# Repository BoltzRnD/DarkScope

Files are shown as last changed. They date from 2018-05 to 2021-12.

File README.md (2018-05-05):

View this project on [CADLAB.io](https://cadlab.io/node/983). 

(DarkScope is Still under development and might take until December 2018 for its first Functional Release.)

Darkscope is an ATSAME70Q21 Based, Open Source and Open Hardware, 4 Channel Portable DSO with Features Such as

1. 3.5" to 7" TFT
2. Internal Storage Options* (64 Mb - 256 Mb)
3. External Storage Support (MicroSD Cards and USB)
4. PC Based Expanded UI for Elaborated and Better Visualizations*.
5. Touch Screen Interface(This will be added at last.)
6. USB Type C Rev interface for Charging and Data Transfer.
7. Up to  5* MSPS (At 1 Active Channel) 
8. Up to  1* MSPS (At 4 Active Channels)

(* Chances are these will be improved by optimizing the firmware on every newer release.)

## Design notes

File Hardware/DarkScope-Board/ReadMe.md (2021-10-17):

# Scope

# HW Sections
1. A Baseboard that hosts All Processing (MCu and Supporting Circuitry, Expansion Ports for- Active Probe Shields, LCD, Switches) (Board 1)
2. Base Active Probe Board. i.e- Analog Channel (Board 2)
3. Battery Management Circuit(BMC) with 1500mAh or more Battery(Board 3)
4. High Speed Active Probe(Board 4)
5. Upto 4 Channel Support (Exposing/Utilizing PA0, PA4, PA5, PA6) (On BaseBoard 1)
6. (Optional) I2C Based Switch Board.(On BaseBoard 1)

Note-
1. LCD "LED-A" connected to 5V for now, can be changed to vcc

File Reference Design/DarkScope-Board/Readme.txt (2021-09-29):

This Folder will be Updated with Schematics and Board Files For the Darkscope.

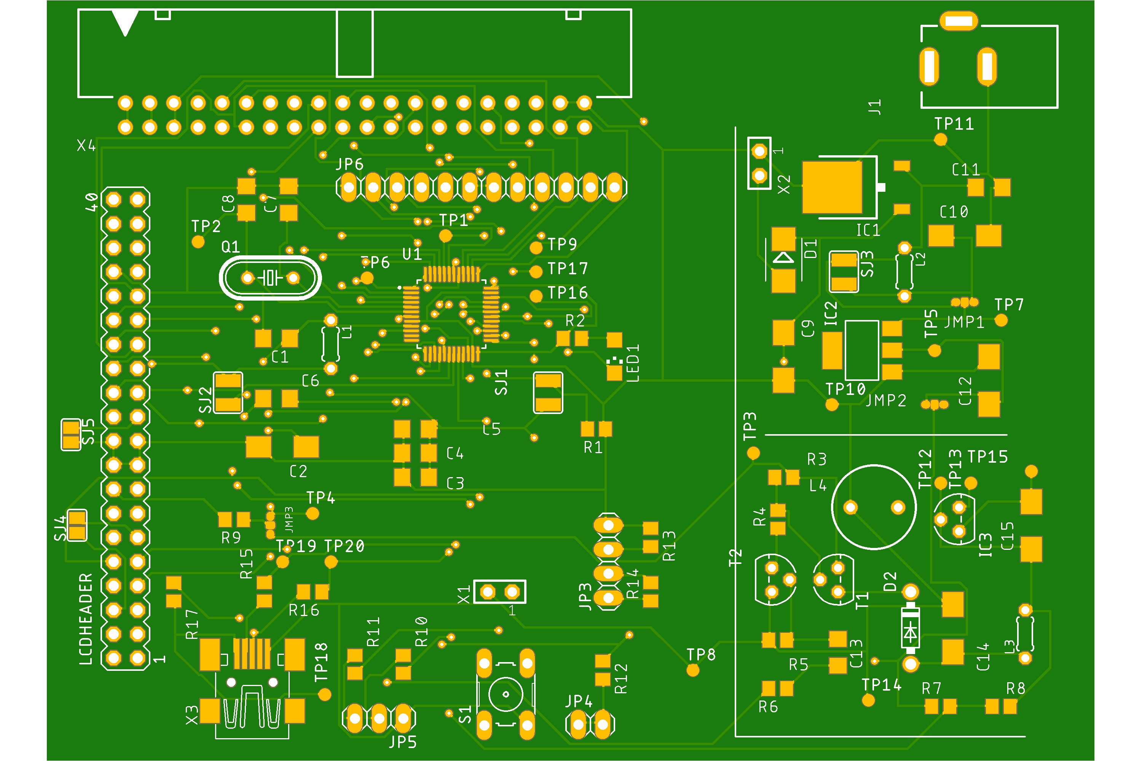
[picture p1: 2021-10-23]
Hardware/DarkScope-Board/BaseBoard.png

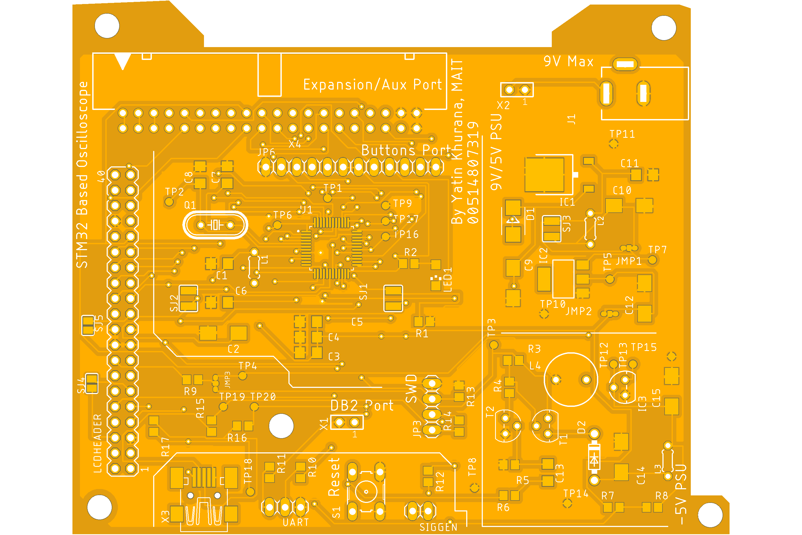
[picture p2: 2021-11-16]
Hardware/DarkScope-Board/BaseBoardOrange.png

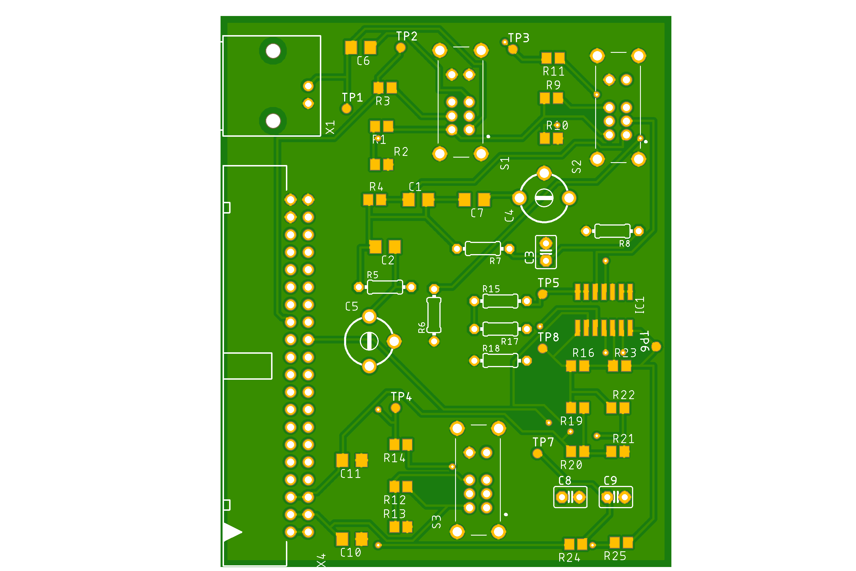
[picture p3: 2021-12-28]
Hardware/DarkScope-Board/Probe.png

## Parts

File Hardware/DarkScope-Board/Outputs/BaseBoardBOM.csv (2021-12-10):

Part | Value | Device | Package | Description | AVAILABILITY | DESCRIPTION | MF | MP | MPN | OC_FARNELL | OC_NEWARK | PACKAGE | POPULARITY | PRICE | PURCHASE-URL | SPICEPREFIX | TP_SIGNAL_NAME
C1 | 0.1u | C-EUC1206 | C1206 | CAPACITOR, European symbol |  |  |  |  |  |  |  |  | 54 |  |  | C
C2 | 100uF | CPOL-USCT6032 | CT6032 | POLARIZED CAPACITOR, American symbol |  |  |  |  |  |  |  |  | 0 |  |  | C
C3 | 0.1u | C-EUC1206 | C1206 | CAPACITOR, European symbol |  |  |  |  |  |  |  |  | 54 |  |  | C
C4 | 0.1u | C-EUC1206 | C1206 | CAPACITOR, European symbol |  |  |  |  |  |  |  |  | 54 |  |  | C
C5 | 0.1u | C-EUC1206 | C1206 | CAPACITOR, European symbol |  |  |  |  |  |  |  |  | 54 |  |  | C
C6 | 0.1u | C-EUC1206 | C1206 | CAPACITOR, European symbol |  |  |  |  |  |  |  |  | 54 |  |  | C
C7 | 22pF | C-EUC1206 | C1206 | CAPACITOR, European symbol |  |  |  |  |  |  |  |  | 54 |  |  | C
C8 | 22pF | C-EUC1206 | C1206 | CAPACITOR, European symbol |  |  |  |  |  |  |  |  | 54 |  |  | C
C9 | 100uF | CPOL-USCT6032 | CT6032 | POLARIZED CAPACITOR, American symbol |  |  |  |  |  |  |  |  | 0 |  |  | C
C10 | 100uF | CPOL-USCT6032 | CT6032 | POLARIZED CAPACITOR, American symbol |  |  |  |  |  |  |  |  | 0 |  |  | C
C11 | 0.1u | C-EUC1206 | C1206 | CAPACITOR, European symbol |  |  |  |  |  |  |  |  | 54 |  |  | C
C12 | 100uF | CPOL-USCT6032 | CT6032 | POLARIZED CAPACITOR, American symbol |  |  |  |  |  |  |  |  | 0 |  |  | C
C13 | 0.1u | C-EUC1206 | C1206 | CAPACITOR, European symbol |  |  |  |  |  |  |  |  | 54 |  |  | C
C14 | 100uF | CPOL-USCT6032 | CT6032 | POLARIZED CAPACITOR, American symbol |  |  |  |  |  |  |  |  | 0 |  |  | C
C15 | 100uF | CPOL-USCT6032 | CT6032 | POLARIZED CAPACITOR, American symbol |  |  |  |  |  |  |  |  | 0 |  |  | C
D1 | SS14 | ES2D | SMB | DIODE |  |  |  |  |  |  |  |  | 3
D2 | 1N5819-B | 1N5819-B | DO41-7.6 | 1.0A SCHOTTKY BARRIER RECTIFIER |  |  |  |  |  |  |  |  | 11
IC1 | 7805DT | 7805DT | TO252 | Positive VOLTAGE REGULATOR |  |  |  |  |  |  |  |  | 0
IC2 | REG1117 | REG1117 | SOT223 | 800mA and 1A Low Dropout (LDO) Positive Regulator |  |  |  |  | REG1117 | 1097566 | 14P6981 |  | 49
IC3 | 7905 | 79L05Z | TO92 | Negative VOLTAGE REGULATOR |  |  |  |  |  |  |  |  | 0
J1 | DCJ0202 | DCJ0202 | DCJ0202 | DC POWER JACK |  |  |  |  |  | unknown | unknown |  | 17
JMP1 | 0R-JUMPC | 0R-JUMPC | C0R-JMP | SMD 0R 0805 Jumper |  |  |  |  |  |  |  |  | 0
JMP2 | 0R-JUMPC | 0R-JUMPC | C0R-JMP | SMD 0R 0805 Jumper |  |  |  |  |  |  |  |  | 0
JMP3 | 0R-JUMPC | 0R-JUMPC | C0R-JMP | SMD 0R 0805 Jumper |  |  |  |  |  |  |  |  | 0
JP3 |  | PINHD-1X4 | 1X04 | PIN HEADER |  |  |  |  |  |  |  |  | 91
JP6 |  | PINHD-1X12 | 1X12 | PIN HEADER |  |  |  |  |  |  |  |  | 28
L1 | 100uH | L-US0204/5 | 0204/5 | INDUCTOR, American symbol |  |  |  |  |  |  |  |  | 0 |  |  | L
L2 | 100uH | L-US0204/5 | 0204/5 | INDUCTOR, American symbol |  |  |  |  |  |  |  |  | 0 |  |  | L
L3 | 100uH | L-US0204/5 | 0204/5 | INDUCTOR, American symbol |  |  |  |  |  |  |  |  | 0 |  |  | L
L4 | 1mH/1A | L-US6000-XXX-RC | 6000-XXXX-RC | INDUCTOR, American symbol |  |  |  |  |  |  |  |  | 5 |  |  | L
LCDHEADER |  | MA20-2 | MA20-2 | PIN HEADER |  |  |  |  |  | unknown | unknown |  | 1
LED1 |  | LEDCHIPLED_1206 | CHIPLED_1206 | LED |  |  |  |  |  |  |  |  | 28
Q1 | 8MHz | CRYSTALHC49S | HC49/S | CRYSTAL |  |  |  |  |  | 1667008 | unknown |  | 49
R1 | 1K | R-US_R0805 | R0805 | RESISTOR, American symbol |  |  |  |  |  |  |  |  | 85 |  |  | R
R2 | 470R | R-US_R0805 | R0805 | RESISTOR, American symbol |  |  |  |  |  |  |  |  | 85 |  |  | R
R3 | 10K | R-US_R0805 | R0805 | RESISTOR, American symbol |  |  |  |  |  |  |  |  | 85 |  |  | R
R4 | 1.5K | R-US_R0805 | R0805 | RESISTOR, American symbol |  |  |  |  |  |  |  |  | 85 |  |  | R
R5 | 10K | R-US_R0805 | R0805 | RESISTOR, American symbol |  |  |  |  |  |  |  |  | 85 |  |  | R
R6 | 470R | R-US_R0805 | R0805 | RESISTOR, American symbol |  |  |  |  |  |  |  |  | 85 |  |  | R
R7 | 1K | R-US_R0805 | R0805 | RESISTOR, American symbol |  |  |  |  |  |  |  |  | 85 |  |  | R
R8 | 10K | R-US_R0805 | R0805 | RESISTOR, American symbol |  |  |  |  |  |  |  |  | 85 |  |  | R
R9 | 180E | R-US_R0805 | R0805 | RESISTOR, American symbol |  |  |  |  |  |  |  |  | 85 |  |  | R
R10 | 1K | R-US_R0805 | R0805 | RESISTOR, American symbol |  |  |  |  |  |  |  |  | 85 |  |  | R
R11 | 1K | R-US_R0805 | R0805 | RESISTOR, American symbol |  |  |  |  |  |  |  |  | 85 |  |  | R
R12 | 1K | R-US_R0805 | R0805 | RESISTOR, American symbol |  |  |  |  |  |  |  |  | 85 |  |  | R
R13 | 10K | R-US_R0805 | R0805 | RESISTOR, American symbol |  |  |  |  |  |  |  |  | 85 |  |  | R
R14 | 10K | R-US_R0805 | R0805 | RESISTOR, American symbol |  |  |  |  |  |  |  |  | 85 |  |  | R
R15 | 22E | R-US_R0805 | R0805 | RESISTOR, American symbol |  |  |  |  |  |  |  |  | 85 |  |  | R
R16 | 22E | R-US_R0805 | R0805 | RESISTOR, American symbol |  |  |  |  |  |  |  |  | 85 |  |  | R
R17 | 1.5K | R-US_R0805 | R0805 | RESISTOR, American symbol |  |  |  |  |  |  |  |  | 85 |  |  | R
S1 |  | 10-XX | B3F-10XX | OMRON SWITCH |  |  |  |  | B3F-1000 | 176432 | 36M3542 |  | 72
SIGGEN |  | PINHD-1X2 | 1X02 | PIN HEADER |  |  |  |  |  |  |  |  | 98
SJ1 |  | SJW | SJW | SMD solder JUMPER |  |  |  |  |  |  |  |  | 3
SJ2 |  | SJW | SJW | SMD solder JUMPER |  |  |  |  |  |  |  |  | 3
SJ3 |  | SJW | SJW | SMD solder JUMPER |  |  |  |  |  |  |  |  | 3
SJ4 |  | SJ | SJ | SMD solder JUMPER |  |  |  |  |  |  |  |  | 33
SJ5 |  | SJ | SJ | SMD solder JUMPER |  |  |  |  |  |  |  |  | 33
T1 | 8550 | #NAME? | TO92 | PNP Transistror |  |  |  |  |  |  |  |  | 0
T2 | 9014 | #NAME? | TO92 | NPN Transistror |  |  |  |  |  |  |  |  | 0
TP1 | TPB1,27 | TPB1,27 | B1,27 | Test pad |  |  |  |  |  |  |  |  | 19
TP2 | TPB1,27 | TPB1,27 | B1,27 | Test pad |  |  |  |  |  |  |  |  | 19
TP3 | TPB1,27 | TPB1,27 | B1,27 | Test pad |  |  |  |  |  |  |  |  | 19
TP4 | TPB1,27 | TPB1,27 | B1,27 | Test pad |  |  |  |  |  |  |  |  | 19
TP5 | TPB1,27 | TPB1,27 | B1,27 | Test pad |  |  |  |  |  |  |  |  | 19
TP6 | TPB1,27 | TPB1,27 | B1,27 | Test pad |  |  |  |  |  |  |  |  | 19
TP7 | TPB1,27 | TPB1,27 | B1,27 | Test pad |  |  |  |  |  |  |  |  | 19
TP8 | TPB1,27 | TPB1,27 | B1,27 | Test pad |  |  |  |  |  |  |  |  | 19
TP9 | TPB1,27 | TPB1,27 | B1,27 | Test pad |  |  |  |  |  |  |  |  | 19
TP10 | TPB1,27 | TPB1,27 | B1,27 | Test pad |  |  |  |  |  |  |  |  | 19
TP11 | TPB1,27 | TPB1,27 | B1,27 | Test pad |  |  |  |  |  |  |  |  | 19
TP12 | TPB1,27 | TPB1,27 | B1,27 | Test pad |  |  |  |  |  |  |  |  | 19
TP13 | TPB1,27 | TPB1,27 | B1,27 | Test pad |  |  |  |  |  |  |  |  | 19
TP14 | TPB1,27 | TPB1,27 | B1,27 | Test pad |  |  |  |  |  |  |  |  | 19
TP15 | TPB1,27 | TPB1,27 | B1,27 | Test pad |  |  |  |  |  |  |  |  | 19
TP16 | TPB1,27 | TPB1,27 | B1,27 | Test pad |  |  |  |  |  |  |  |  | 19
TP17 | TPB1,27 | TPB1,27 | B1,27 | Test pad |  |  |  |  |  |  |  |  | 19
TP18 | TPB1,27 | TPB1,27 | B1,27 | Test pad |  |  |  |  |  |  |  |  | 19
TP19 | TPB1,27 | TPB1,27 | B1,27 | Test pad |  |  |  |  |  |  |  |  | 19
TP20 | TPB1,27 | TPB1,27 | B1,27 | Test pad |  |  |  |  |  |  |  |  | 19
U1 | STM32F103CBT6 | STM32F103CBT6 | QFP50P900X900X160-48N | Mainstream Performance line, ARM Cortex-M3 MCU with 128 Kbytes Flash, 72 MHz CPU, motor control, USB and CAN Check prices | In Stock | ARM® Cortex®-M3 STM32F1 Microcontroller IC 32-Bit 72MHz 128KB (128K x 8) FLASH | STMicroelectronics | STM32F103CBT6 |  |  |  | LQFP-48 STMicroelectronics |  | None | https://pricing.snapeda.com/search/part/STM32F103CBT6/?ref=eda
UART |  | PINHD-1X3 | 1X03 | PIN HEADER |  |  |  |  |  |  |  |  | 92
X1 | TSW-102-07-G-S | TSW-102-07-G-S | TSW-102-XX-G-S | THROUGH-HOLE .025 SQ POST HEADER" |  |  | Samtec Inc. |  | TSW-102-07-G-S
X2 | TSW-102-07-G-S | TSW-102-07-G-S | TSW-102-XX-G-S | THROUGH-HOLE .025 SQ POST HEADER" |  |  | Samtec Inc. |  | TSW-102-07-G-S
X3 | MINI-USB-32005-301 | MINI-USB-32005-301 | 32005-301 | MINI USB-B Conector |  |  |  |  |  | unknown | unknown |  | 0
X4 | 2540-5 | 2540-5 | PAK100/2500-5-40 | 3M (TM) Pak 100 4-Wall Header |  |  |  |  |  | 9838414 | unknown |  | 0

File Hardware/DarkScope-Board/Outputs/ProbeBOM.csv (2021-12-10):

Part | Value | Device | Package | Description | ARROW_PART_NUMBER | ARROW_PRICE-STOCK | DESCRIPTION | HEIGHT | MANUFACTURER_NAME | MANUFACTURER_PART_NUMBER | MF | MOUSER_PART_NUMBER | MOUSER_PRICE-STOCK | MPN | OC_FARNELL | OC_NEWARK | POPULARITY | SPICEPREFIX | TP_SIGNAL_NAME
C1 | 220pF | C-EUC1206 | C1206 | CAPACITOR, European symbol |  |  |  |  |  |  |  |  |  |  |  |  | 54 | C
C2 | 3pF | C-EUC1206 | C1206 | CAPACITOR, European symbol |  |  |  |  |  |  |  |  |  |  |  |  | 54 | C
C3 | 120pF | C2,5-3 | C2.5-3 | CAPACITOR |  |  |  |  |  |  |  |  |  |  |  |  | 38
C4 | 30pF | C-TRIMM808 | CTRIM808-BC | Trimm capacitor |  |  |  |  |  |  |  |  |  |  |  |  | 3 | C
C5 | 30pF | C-TRIMM808 | CTRIM808-BC | Trimm capacitor |  |  |  |  |  |  |  |  |  |  |  |  | 3 | C
C6 | 0.1u | C-EUC1206 | C1206 | CAPACITOR, European symbol |  |  |  |  |  |  |  |  |  |  |  |  | 54 | C
C7 | 1pF | C-EUC1206 | C1206 | CAPACITOR, European symbol |  |  |  |  |  |  |  |  |  |  |  |  | 54 | C
C8 | 120pF | C2,5-3 | C2.5-3 | CAPACITOR |  |  |  |  |  |  |  |  |  |  |  |  | 38
C9 | 0.1u | C2,5-3 | C2.5-3 | CAPACITOR |  |  |  |  |  |  |  |  |  |  |  |  | 38
C10 | 0.1uF | C-EUC1206 | C1206 | CAPACITOR, European symbol |  |  |  |  |  |  |  |  |  |  |  |  | 54 | C
C11 | 0.1uF | C-EUC1206 | C1206 | CAPACITOR, European symbol |  |  |  |  |  |  |  |  |  |  |  |  | 54 | C
IC1 | TL084D | TL084D | SO14 | OP AMP |  |  |  |  |  |  |  |  |  |  |  |  | 4 | X
R1 | 10K | R-US_R0805 | R0805 | RESISTOR, American symbol |  |  |  |  |  |  |  |  |  |  |  |  | 85 | R
R2 | 3.3K | R-US_R0805 | R0805 | RESISTOR, American symbol |  |  |  |  |  |  |  |  |  |  |  |  | 85 | R
R3 | 1.5K | R-US_R0805 | R0805 | RESISTOR, American symbol |  |  |  |  |  |  |  |  |  |  |  |  | 85 | R
R4 | 100K | R-US_R0805 | R0805 | RESISTOR, American symbol |  |  |  |  |  |  |  |  |  |  |  |  | 85 | R
R5 | 1.8M 1% | R-EU_0204/7 | 0204/7 | RESISTOR, European symbol |  |  |  |  |  |  |  |  |  |  |  |  | 79 | R
R6 | 200K 1% | R-EU_0204/7 | 0204/7 | RESISTOR, European symbol |  |  |  |  |  |  |  |  |  |  |  |  | 79 | R
R7 | 2M 1% | R-EU_0204/7 | 0204/7 | RESISTOR, European symbol |  |  |  |  |  |  |  |  |  |  |  |  | 79 | R
R8 | 20K 1% | R-EU_0204/7 | 0204/7 | RESISTOR, European symbol |  |  |  |  |  |  |  |  |  |  |  |  | 79 | R
R9 | 10K | R-US_R0805 | R0805 | RESISTOR, American symbol |  |  |  |  |  |  |  |  |  |  |  |  | 85 | R
R10 | 3.3K | R-US_R0805 | R0805 | RESISTOR, American symbol |  |  |  |  |  |  |  |  |  |  |  |  | 85 | R
R11 | 1.5K | R-US_R0805 | R0805 | RESISTOR, American symbol |  |  |  |  |  |  |  |  |  |  |  |  | 85 | R
R12 | 10K | R-US_R0805 | R0805 | RESISTOR, American symbol |  |  |  |  |  |  |  |  |  |  |  |  | 85 | R
R13 | 3.3K | R-US_R0805 | R0805 | RESISTOR, American symbol |  |  |  |  |  |  |  |  |  |  |  |  | 85 | R
R14 | 1.5K | R-US_R0805 | R0805 | RESISTOR, American symbol |  |  |  |  |  |  |  |  |  |  |  |  | 85 | R
R15 | 300E | R-EU_0204/7 | 0204/7 | RESISTOR, European symbol |  |  |  |  |  |  |  |  |  |  |  |  | 79 | R
R16 | 120e | R-US_R0805 | R0805 | RESISTOR, American symbol |  |  |  |  |  |  |  |  |  |  |  |  | 85 | R
R17 | 180E | R-EU_0204/7 | 0204/7 | RESISTOR, European symbol |  |  |  |  |  |  |  |  |  |  |  |  | 79 | R
R18 | 120E | R-EU_0204/7 | 0204/7 | RESISTOR, European symbol |  |  |  |  |  |  |  |  |  |  |  |  | 79 | R
R19 | 1K | R-US_R0805 | R0805 | RESISTOR, American symbol |  |  |  |  |  |  |  |  |  |  |  |  | 85 | R
R20 | 3K | R-US_R0805 | R0805 | RESISTOR, American symbol |  |  |  |  |  |  |  |  |  |  |  |  | 85 | R
R21 | 150E | R-US_R0805 | R0805 | RESISTOR, American symbol |  |  |  |  |  |  |  |  |  |  |  |  | 85 | R
R22 | 120E | R-US_R0805 | R0805 | RESISTOR, American symbol |  |  |  |  |  |  |  |  |  |  |  |  | 85 | R
R23 | 100k | R-US_R0805 | R0805 | RESISTOR, American symbol |  |  |  |  |  |  |  |  |  |  |  |  | 85 | R
R24 | 100K | R-US_R0805 | R0805 | RESISTOR, American symbol |  |  |  |  |  |  |  |  |  |  |  |  | 85 | R
R25 | 1k | R-US_R0805 | R0805 | RESISTOR, American symbol |  |  |  |  |  |  |  |  |  |  |  |  | 85 | R
S1 | DC-AC-GND | EG2301 | EG2301 | Slide Switches DP3T PC MNT SLIDE |  |  | Slide Switches DP3T PC MNT SLIDE | 11mm | E-Switch | EG2301 |  | 612-EG2301 | https://www.mouser.co.uk/ProductDetail/E-Switch/EG2301?qs=6C6BR4UgC3MjpdLgLKoVKg%3D%3D
S2 | EG2301 | EG2301 | EG2301 | Slide Switches DP3T PC MNT SLIDE |  |  | Slide Switches DP3T PC MNT SLIDE | 11mm | E-Switch | EG2301 |  | 612-EG2301 | https://www.mouser.co.uk/ProductDetail/E-Switch/EG2301?qs=6C6BR4UgC3MjpdLgLKoVKg%3D%3D
S3 | EG2301 | EG2301 | EG2301 | Slide Switches DP3T PC MNT SLIDE |  |  | Slide Switches DP3T PC MNT SLIDE | 11mm | E-Switch | EG2301 |  | 612-EG2301 | https://www.mouser.co.uk/ProductDetail/E-Switch/EG2301?qs=6C6BR4UgC3MjpdLgLKoVKg%3D%3D
TP1 | TPB1,27 | TPB1,27 | B1,27 | Test pad |  |  |  |  |  |  |  |  |  |  |  |  | 19
TP2 | TPB1,27 | TPB1,27 | B1,27 | Test pad |  |  |  |  |  |  |  |  |  |  |  |  | 19
TP3 | TPB1,27 | TPB1,27 | B1,27 | Test pad |  |  |  |  |  |  |  |  |  |  |  |  | 19
TP4 | TPB1,27 | TPB1,27 | B1,27 | Test pad |  |  |  |  |  |  |  |  |  |  |  |  | 19
TP5 | TPB1,27 | TPB1,27 | B1,27 | Test pad |  |  |  |  |  |  |  |  |  |  |  |  | 19
TP6 | TPB1,27 | TPB1,27 | B1,27 | Test pad |  |  |  |  |  |  |  |  |  |  |  |  | 19
TP7 | TPB1,27 | TPB1,27 | B1,27 | Test pad |  |  |  |  |  |  |  |  |  |  |  |  | 19
TP8 | TPB1,27 | TPB1,27 | B1,27 | Test pad |  |  |  |  |  |  |  |  |  |  |  |  | 19
X1 | 1-227161-0 | 1-227161-0 | AMP_227161 | JACK, RIGHT ANGLE, 50 OHM, PCB, BNC |  |  |  |  |  |  | TYCO ELECTRONICS |  |  | 1-227161 | unknown | 33B3200 | 0
X4 | 2540-5 | 2540-5 | PAK100/2500-5-40 | 3M (TM) Pak 100 4-Wall Header |  |  |  |  |  |  |  |  |  |  | 9838414 | unknown | 0

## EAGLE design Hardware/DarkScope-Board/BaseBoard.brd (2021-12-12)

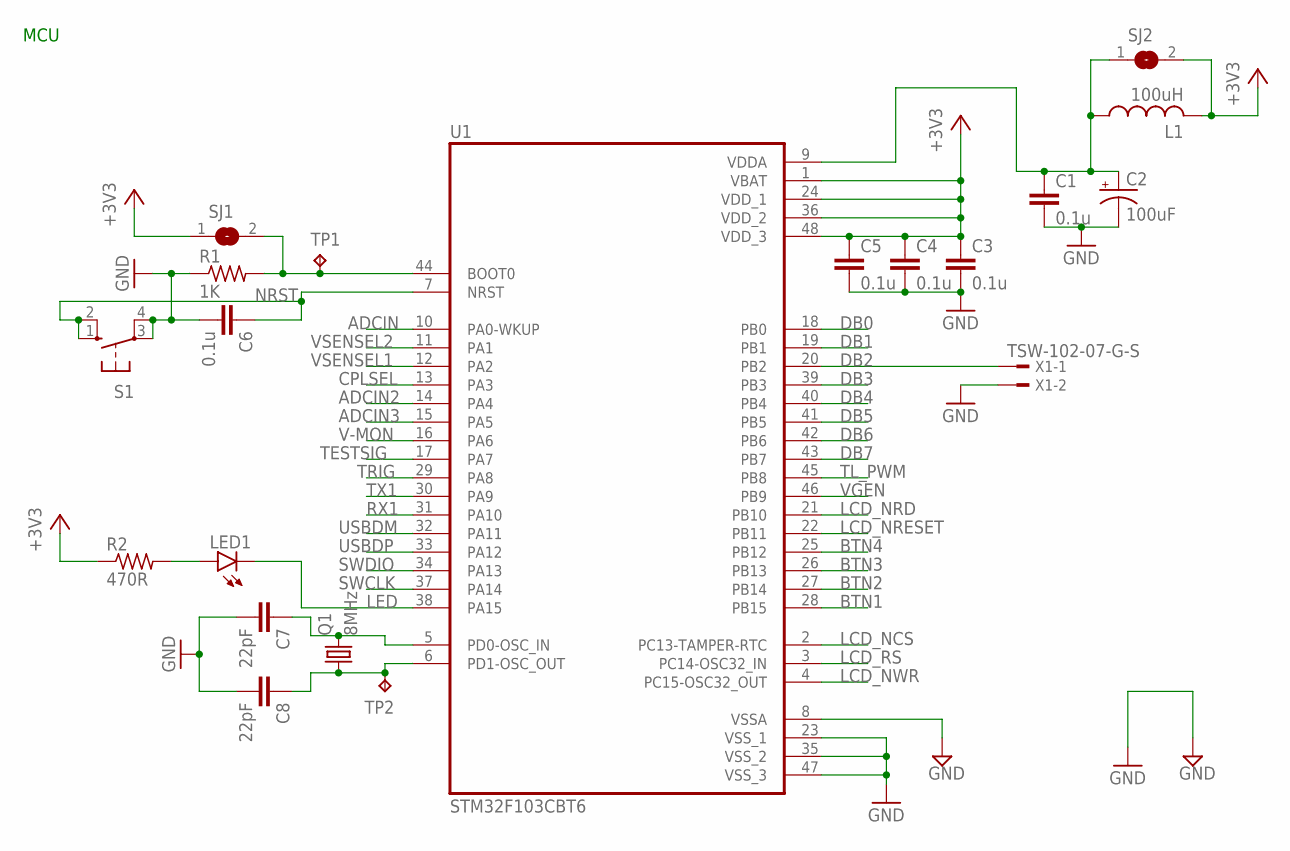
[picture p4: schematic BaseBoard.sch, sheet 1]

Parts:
C1, C3, C4, C5, C6: 0.1u; C1206
C2: 100uF; CT6032
C7, C8: 22pF; C1206
L1: 100uH; 0204/5
LED1: LEDCHIPLED_1206; CHIPLED_1206
Q1: 8MHz; HC49/S
R1: 1K; R0805
R2: 470R; R0805
S1: 10-XX; B3F-10XX
SJ1, SJ2: SJW
TP1, TP2: TPB1,27; B1,27
U1: STM32F103CBT6; QFP50P900X900X160-48N
X1: TSW-102-07-G-S; TSW-102-XX-G-S

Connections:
+3V3: C3.1, C4.1, C5.1, L1.2, R2.1, SJ1.1, SJ2.2, U1.1 (VBAT), U1.24 (VDD_1), U1.36 (VDD_2), U1.48 (VDD_3); also elsewhere on the board
ADCIN: U1.10 (PA0-WKUP); also elsewhere on the board
ADCIN2: U1.14 (PA4); also elsewhere on the board
ADCIN3: U1.15 (PA5); also elsewhere on the board
BTN1: U1.28 (PB15); also elsewhere on the board
BTN2: U1.27 (PB14); also elsewhere on the board
BTN3: U1.26 (PB13); also elsewhere on the board
BTN4: U1.25 (PB12); also elsewhere on the board
CPLSEL: U1.13 (PA3); also elsewhere on the board
DB0: U1.18 (PB0); also elsewhere on the board
DB1: U1.19 (PB1); also elsewhere on the board
DB2: U1.20 (PB2), X1.1; also elsewhere on the board
DB3: U1.39 (PB3); also elsewhere on the board
DB4: U1.40 (PB4); also elsewhere on the board
DB5: U1.41 (PB5); also elsewhere on the board
DB6: U1.42 (PB6); also elsewhere on the board
DB7: U1.43 (PB7); also elsewhere on the board
GND: C1.2, C2.-, C3.2, C4.2, C5.2, C6.2, C7.2, C8.2, R1.1, S1.3, S1.4 (P1), U1.8 (VSSA), U1.23 (VSS_1), U1.35 (VSS_2), U1.47 (VSS_3), X1.2; also elsewhere on the board
LCD_NCS: U1.2 (PC13-TAMPER-RTC); also elsewhere on the board
LCD_NRD: U1.21 (PB10); also elsewhere on the board
LCD_NRESET: U1.22 (PB11); also elsewhere on the board
LCD_NWR: U1.4 (PC15-OSC32_OUT); also elsewhere on the board
LCD_RS: U1.3 (PC14-OSC32_IN); also elsewhere on the board
LED: LED1.C, U1.38 (PA15); also elsewhere on the board
unnamed: C1.1, C2.+, L1.1, SJ2.1, U1.9 (VDDA)
unnamed: LED1.A, R2.2
unnamed: R1.2, SJ1.2, TP1.TP, U1.44 (BOOT0)
unnamed: C7.1, Q1.2, U1.5 (PD0-OSC_IN)
unnamed: C8.1, Q1.1, TP2.TP, U1.6 (PD1-OSC_OUT)
NRST: C6.1, S1.1 (S), S1.2 (S1), U1.7 (NRST); also elsewhere on the board
RX1: U1.31 (PA10); also elsewhere on the board
SWCLK: U1.37 (PA14); also elsewhere on the board
SWDIO: U1.34 (PA13); also elsewhere on the board
TESTSIG: U1.17 (PA7); also elsewhere on the board
TL_PWM: U1.45 (PB8); also elsewhere on the board
TRIG: U1.29 (PA8); also elsewhere on the board
TX1: U1.30 (PA9); also elsewhere on the board
USBDM: U1.32 (PA11); also elsewhere on the board
USBDP: U1.33 (PA12); also elsewhere on the board
V-MON: U1.16 (PA6); also elsewhere on the board
VGEN: U1.46 (PB9); also elsewhere on the board
VSENSEL1: U1.12 (PA2); also elsewhere on the board
VSENSEL2: U1.11 (PA1); also elsewhere on the board

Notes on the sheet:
MCU

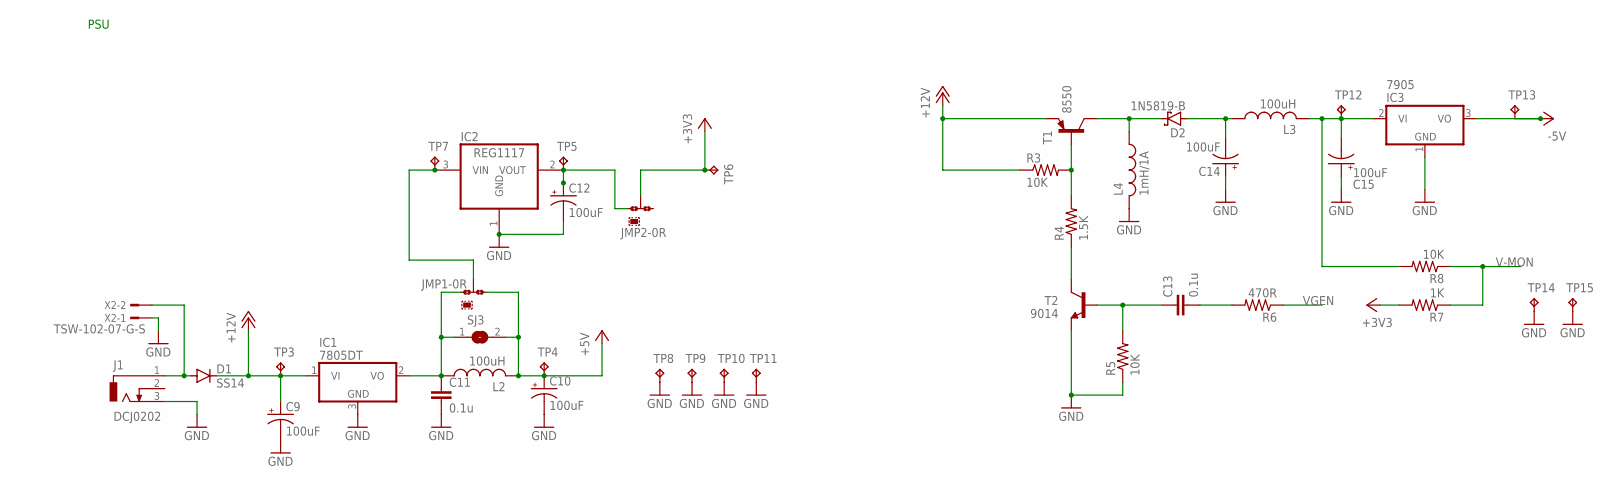
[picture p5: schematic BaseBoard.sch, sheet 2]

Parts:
C9, C10, C12, C14, C15: 100uF; CT6032
C11, C13: 0.1u; C1206
D1: SS14; SMB
D2: 1N5819-B; DO41-7.6
IC1: 7805DT; TO252
IC2: REG1117; SOT223
IC3: 7905; TO92
J1: DCJ0202
JMP1, JMP2: 0R-JUMPA; A0R-JMP
L2, L3: 100uH; 0204/5
L4: 1mH/1A; 6000-XXXX-RC
R3, R5, R8: 10K; R0805
R4: 1.5K; R0805
R6: 470R; R0805
R7: 1K; R0805
SJ3: SJW
T1: 8550; TO92
T2: 9014; TO92
TP3, TP4, TP5, TP6, TP7, TP8, TP9, TP10, TP11, TP12, TP13, TP14, TP15: TPB1,27; B1,27
X2: TSW-102-07-G-S; TSW-102-XX-G-S

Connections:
+3V3: JMP2.2, R7.2, TP6.TP; also elsewhere on the board
+5V: C10.+, JMP1.3, L2.2, SJ3.2, TP4.TP; also elsewhere on the board
+12V: C9.+, D1.C, IC1.1 (VI), R3.1, T1.1 (E), TP3.TP; also elsewhere on the board
-5V: IC3.3 (VO), TP13.TP; also elsewhere on the board
GND: C9.-, C10.-, C11.2, C12.-, C14.+, C15.+, IC1.3 (GND), IC2.1 (GND), IC3.1 (GND), J1.3, L4.2, R5.1, T2.1 (E), TP8.TP, TP9.TP, TP10.TP, TP11.TP, TP14.TP, TP15.TP, X2.1; also elsewhere on the board
unnamed: C11.1, IC1.2 (VO), JMP1.1, L2.1, SJ3.1
unnamed: R3.2, R4.2, T1.2 (B)
unnamed: C12.+, IC2.2 (VOUT), JMP2.1, TP5.TP
unnamed: R4.1, T2.3 (C)
unnamed: C13.1, R5.2, T2.2 (B)
unnamed: IC2.3 (VIN), JMP1.2, TP7.TP
unnamed: C13.2, R6.2
unnamed: D2.C, L4.1, T1.3 (C)
unnamed: C14.-, D2.A, L3.1
unnamed: C15.-, IC3.2 (VI), L3.2, R8.2, TP12.TP
unnamed: D1.A, J1.1, X2.2
V-MON: R7.1, R8.1; also elsewhere on the board
VGEN: R6.1; also elsewhere on the board

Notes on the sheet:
PSU

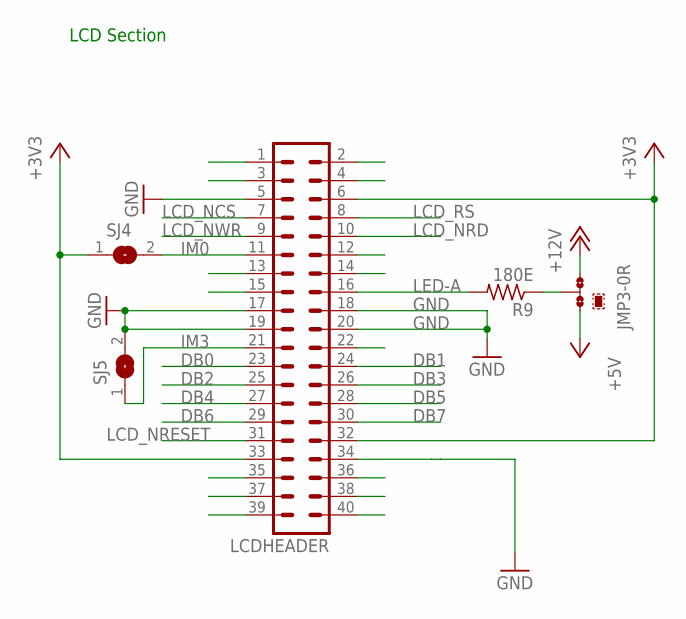
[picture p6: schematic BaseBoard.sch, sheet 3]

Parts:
JMP3: 0R-JUMPA; A0R-JMP
LCDHEADER: MA20-2
R9: 180E; R0805
SJ4, SJ5: SJ

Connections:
+3V3: LCDHEADER.6, LCDHEADER.32, LCDHEADER.33, SJ4.1; also elsewhere on the board
+5V: JMP3.1; also elsewhere on the board
+12V: JMP3.3; also elsewhere on the board
DB0: LCDHEADER.23; also elsewhere on the board
DB1: LCDHEADER.24; also elsewhere on the board
DB2: LCDHEADER.25; also elsewhere on the board
DB3: LCDHEADER.26; also elsewhere on the board
DB4: LCDHEADER.27; also elsewhere on the board
DB5: LCDHEADER.28; also elsewhere on the board
DB6: LCDHEADER.29; also elsewhere on the board
DB7: LCDHEADER.30; also elsewhere on the board
GND: LCDHEADER.5, LCDHEADER.17, LCDHEADER.18, LCDHEADER.19, LCDHEADER.20, LCDHEADER.34, SJ5.2; also elsewhere on the board
IM0: LCDHEADER.11, SJ4.2
IM3: LCDHEADER.21, SJ5.1
LCD_NCS: LCDHEADER.7; also elsewhere on the board
LCD_NRD: LCDHEADER.10; also elsewhere on the board
LCD_NRESET: LCDHEADER.31; also elsewhere on the board
LCD_NWR: LCDHEADER.9; also elsewhere on the board
LCD_RS: LCDHEADER.8; also elsewhere on the board
LED-A: LCDHEADER.16, R9.2
LED-K1: LCDHEADER.15
unnamed: JMP3.2, R9.1

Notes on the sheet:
LCD Section

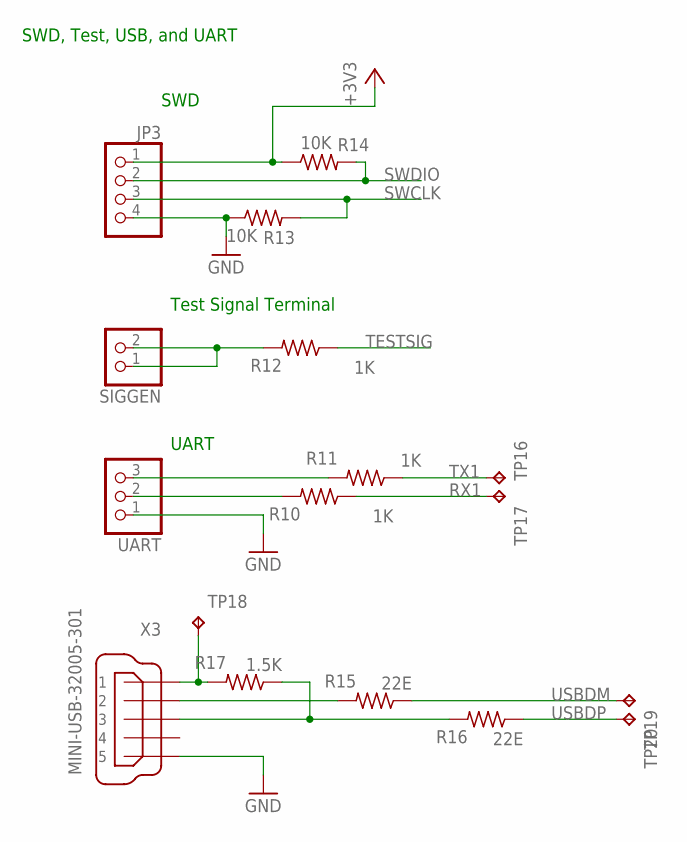
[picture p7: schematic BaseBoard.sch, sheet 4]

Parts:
JP3: PINHD-1X4; 1X04
R10, R11, R12: 1K; R0805
R13, R14: 10K; R0805
R15, R16: 22E; R0805
R17: 1.5K; R0805
SIGGEN: PINHD-1X2; 1X02
TP16, TP17, TP18, TP19, TP20: TPB1,27; B1,27
UART: PINHD-1X3; 1X03
X3: MINI-USB-32005-301; 32005-301

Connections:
+3V3: JP3.1, R14.1; also elsewhere on the board
GND: JP3.4, R13.1, UART.1, X3.5; also elsewhere on the board
unnamed: R10.2, UART.2
unnamed: R11.2, UART.3
unnamed: R12.2, SIGGEN.1, SIGGEN.2
unnamed: R17.2, TP18.TP, X3.1
unnamed: R16.2, R17.1, X3.3
unnamed: R15.2, X3.2
RX1: R10.1, TP17.TP; also elsewhere on the board
SWCLK: JP3.3, R13.2; also elsewhere on the board
SWDIO: JP3.2, R14.2; also elsewhere on the board
TESTSIG: R12.1; also elsewhere on the board
TX1: R11.1, TP16.TP; also elsewhere on the board
USBDM: R15.1, TP19.TP; also elsewhere on the board
USBDP: R16.1, TP20.TP; also elsewhere on the board

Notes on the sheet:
SWD, Test, USB, and UART
UART
Test Signal Terminal
SWD

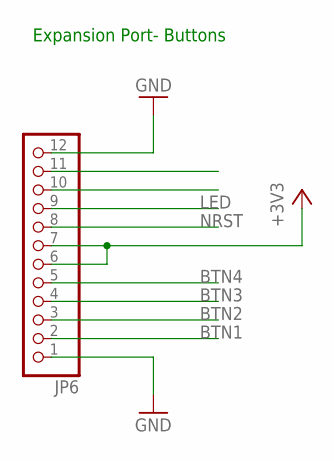
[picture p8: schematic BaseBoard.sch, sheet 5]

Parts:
JP6: PINHD-1X12; 1X12

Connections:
+3V3: JP6.6, JP6.7; also elsewhere on the board
BTN1: JP6.2; also elsewhere on the board
BTN2: JP6.3; also elsewhere on the board
BTN3: JP6.4; also elsewhere on the board
BTN4: JP6.5; also elsewhere on the board
GND: JP6.1, JP6.12; also elsewhere on the board
LED: JP6.9; also elsewhere on the board
NRST: JP6.8; also elsewhere on the board

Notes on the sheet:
Expansion Port- Buttons

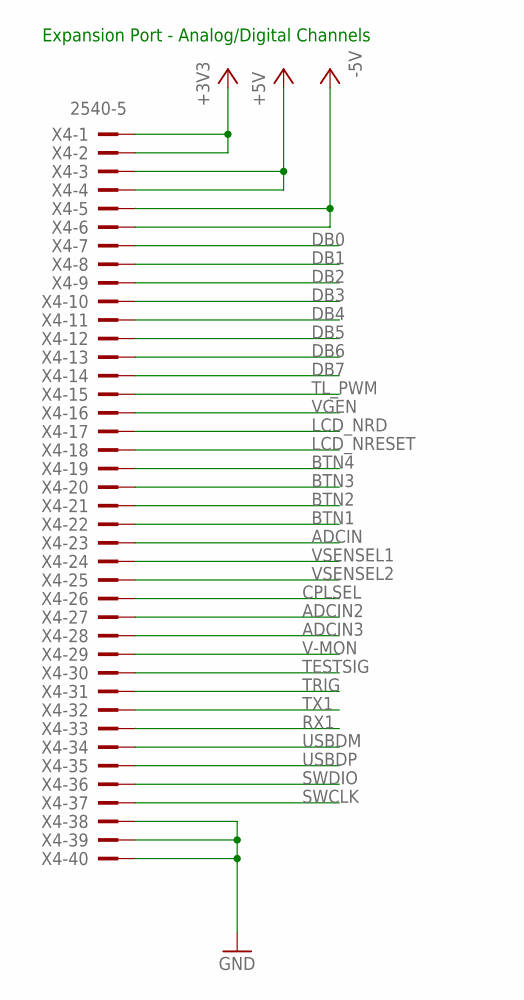
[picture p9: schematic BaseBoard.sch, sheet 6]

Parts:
X4: 2540-5; PAK100/2500-5-40

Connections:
+3V3: X4.1, X4.2; also elsewhere on the board
+5V: X4.3, X4.4; also elsewhere on the board
-5V: X4.5, X4.6; also elsewhere on the board
ADCIN: X4.23; also elsewhere on the board
ADCIN2: X4.27; also elsewhere on the board
ADCIN3: X4.28; also elsewhere on the board
BTN1: X4.22; also elsewhere on the board
BTN2: X4.21; also elsewhere on the board
BTN3: X4.20; also elsewhere on the board
BTN4: X4.19; also elsewhere on the board
CPLSEL: X4.26; also elsewhere on the board
DB0: X4.7; also elsewhere on the board
DB1: X4.8; also elsewhere on the board
DB2: X4.9; also elsewhere on the board
DB3: X4.10; also elsewhere on the board
DB4: X4.11; also elsewhere on the board
DB5: X4.12; also elsewhere on the board
DB6: X4.13; also elsewhere on the board
DB7: X4.14; also elsewhere on the board
GND: X4.38, X4.39, X4.40; also elsewhere on the board
LCD_NRD: X4.17; also elsewhere on the board
LCD_NRESET: X4.18; also elsewhere on the board
RX1: X4.33; also elsewhere on the board
SWCLK: X4.37; also elsewhere on the board
SWDIO: X4.36; also elsewhere on the board
TESTSIG: X4.30; also elsewhere on the board
TL_PWM: X4.15; also elsewhere on the board
TRIG: X4.31; also elsewhere on the board
TX1: X4.32; also elsewhere on the board
USBDM: X4.34; also elsewhere on the board
USBDP: X4.35; also elsewhere on the board
V-MON: X4.29; also elsewhere on the board
VGEN: X4.16; also elsewhere on the board
VSENSEL1: X4.24; also elsewhere on the board
VSENSEL2: X4.25; also elsewhere on the board

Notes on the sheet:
Expansion Port - Analog/Digital Channels

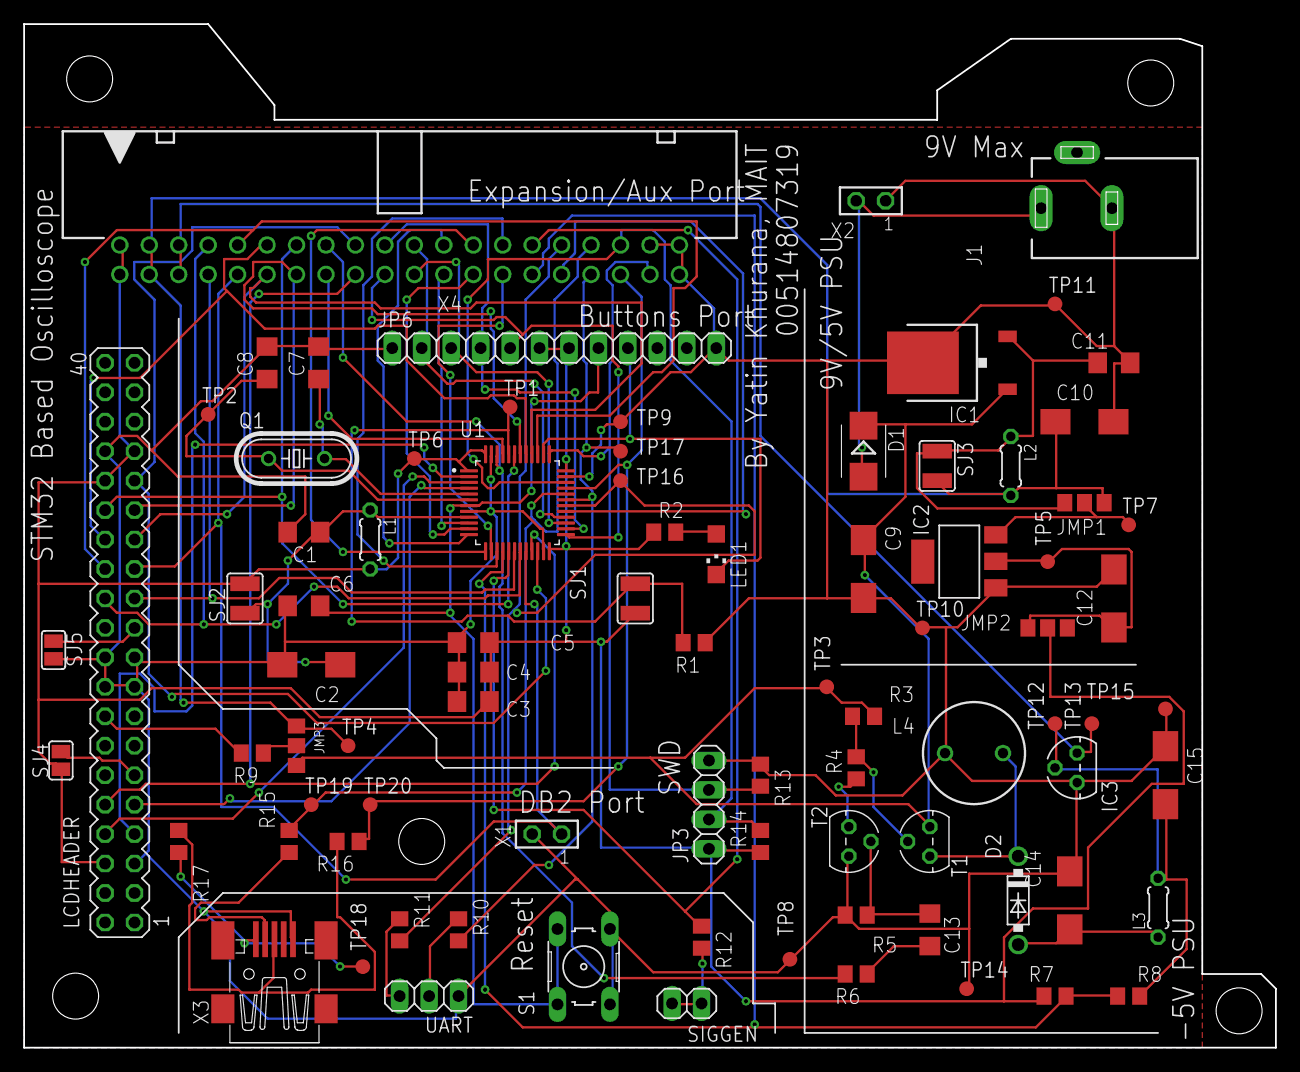
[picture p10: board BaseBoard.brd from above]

Board: 2 copper layers, 108.0 x 88.3 mm, 90 parts (0 on the bottom side), 67 nets.

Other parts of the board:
U$1, U$2, U$3, U$4, U$5: DRILL_0.1560

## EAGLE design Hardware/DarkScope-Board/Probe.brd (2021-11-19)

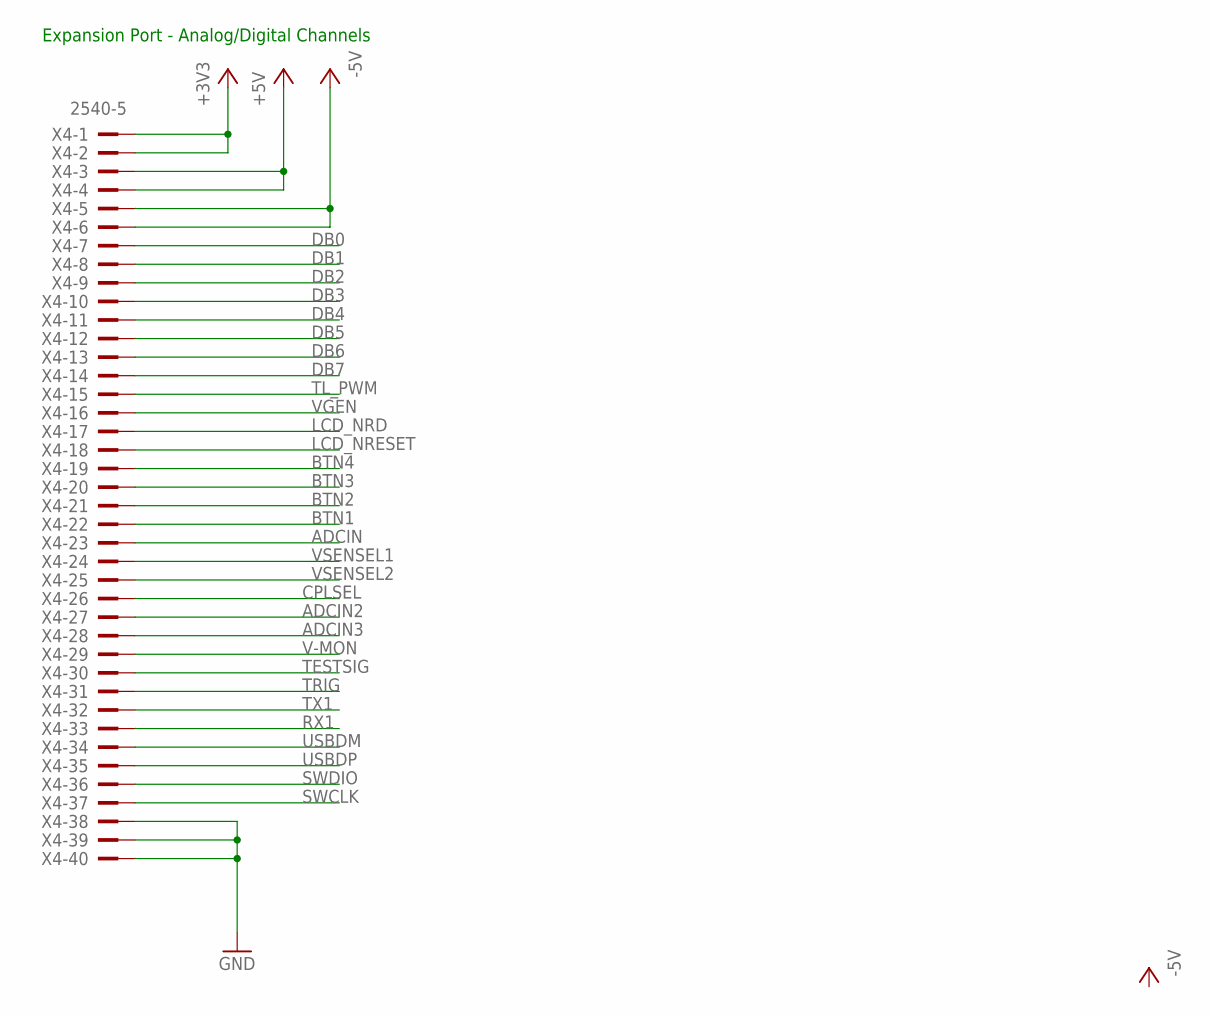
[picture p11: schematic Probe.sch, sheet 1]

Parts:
X4: 2540-5; PAK100/2500-5-40

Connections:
+3V3: X4.1, X4.2
+5V: X4.3, X4.4; also elsewhere on the board
-5V: X4.5, X4.6; also elsewhere on the board
ADCIN: X4.23; also elsewhere on the board
ADCIN2: X4.27
ADCIN3: X4.28
BTN1: X4.22
BTN2: X4.21
BTN3: X4.20
BTN4: X4.19
CPLSEL: X4.26; also elsewhere on the board
DB0: X4.7
DB1: X4.8
DB2: X4.9
DB3: X4.10
DB4: X4.11
DB5: X4.12
DB6: X4.13
DB7: X4.14
GND: X4.38, X4.39, X4.40; also elsewhere on the board
LCD_NRD: X4.17
LCD_NRESET: X4.18
RX1: X4.33
SWCLK: X4.37
SWDIO: X4.36
TESTSIG: X4.30
TL_PWM: X4.15; also elsewhere on the board
TRIG: X4.31; also elsewhere on the board
TX1: X4.32
USBDM: X4.34
USBDP: X4.35
V-MON: X4.29
VGEN: X4.16
VSENSEL1: X4.24; also elsewhere on the board
VSENSEL2: X4.25; also elsewhere on the board

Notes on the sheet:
Expansion Port - Analog/Digital Channels

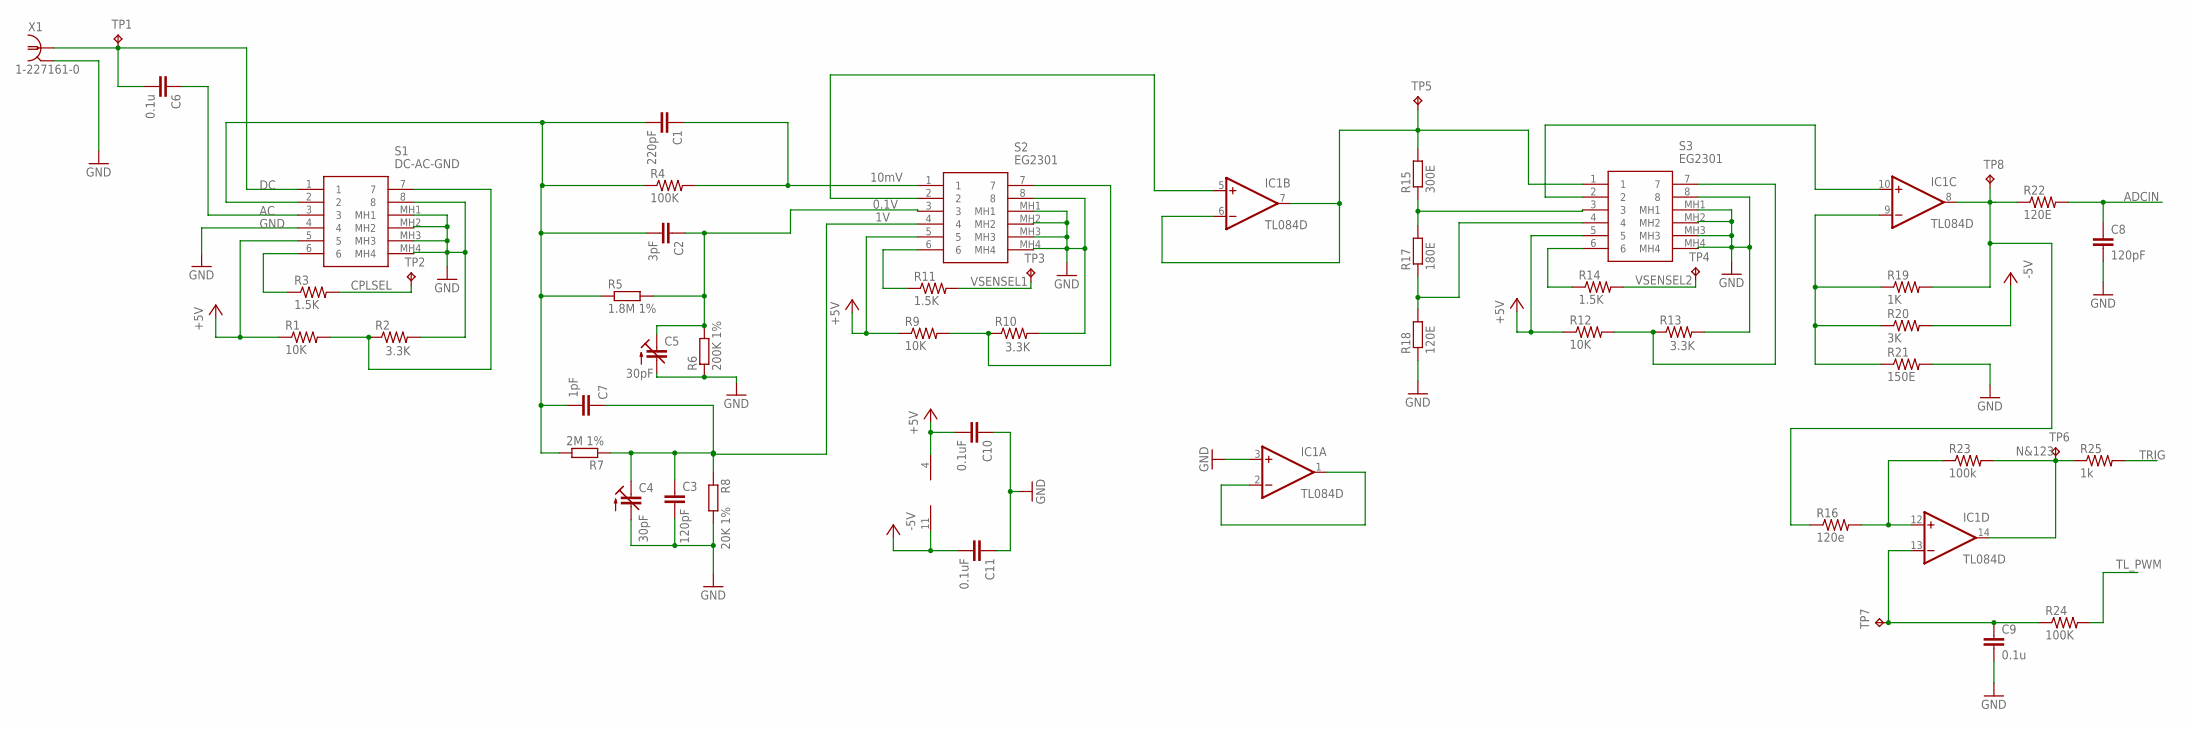
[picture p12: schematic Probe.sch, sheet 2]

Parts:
C1: 220pF; C1206
C2: 3pF; C1206
C3, C8: 120pF; C2.5-3
C4, C5: 30pF; CTRIM808-BC
C6: 0.1u; C1206
C7: 1pF; C1206
C9: 0.1u; C2.5-3
C10, C11: 0.1uF; C1206
IC1: TL084D; SO14
R1, R9, R12: 10K; R0805
R2, R10, R13: 3.3K; R0805
R3, R11, R14: 1.5K; R0805
R4, R24: 100K; R0805
R5: 1.8M 1%; 0204/7
R6: 200K 1%; 0204/7
R7: 2M 1%; 0204/7
R8: 20K 1%; 0204/7
R15: 300E; 0204/7
R16: 120e; R0805
R17: 180E; 0204/7
R18: 120E; 0204/7
R19: 1K; R0805
R20: 3K; R0805
R21: 150E; R0805
R22: 120E; R0805
R23: 100k; R0805
R25: 1k; R0805
S1: DC-AC-GND; EG2301
S2, S3: EG2301
TP1, TP2, TP3, TP4, TP5, TP6, TP7, TP8: TPB1,27; B1,27
X1: 1-227161-0; AMP_227161

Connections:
+5V: C10.2, IC1.4 (V+), R1.1, R9.1, R12.1, S1.5, S2.5, S3.5; also elsewhere on the board
-5V: C11.2, IC1.11 (V-), R20.2; also elsewhere on the board
ADCIN: C8.1, R22.2; also elsewhere on the board
CPLSEL: R3.2, TP2.TP; also elsewhere on the board
GND: C3.2, C4.2 (A), C5.2 (A), C8.2, C9.2, C10.1, C11.1, IC1.3 (+IN), R2.2, R6.1, R8.2, R10.2, R13.2, R18.1, R21.2, S1.4, S1.8, S1.MH1, S1.MH2, S1.MH3, S1.MH4, S2.8, S2.MH1, S2.MH2, S2.MH3, S2.MH4, S3.8, S3.MH1, S3.MH2, S3.MH3, S3.MH4, X1.2; also elsewhere on the board
unnamed: C6.2, S1.1, TP1.TP, X1.1
unnamed: C6.1, S1.3
unnamed: R3.1, S1.6
unnamed: R1.2, R2.1, S1.7
unnamed: C1.2, C2.2, C7.2, R4.1, R5.1, R7.2, S1.2
unnamed: C3.1, C4.1 (E), C7.1, R7.1, R8.1, S2.4
unnamed: C1.1, R4.2, S2.1
unnamed: C2.1, C5.1 (E), R5.2, R6.2, S2.3
unnamed: IC1.5 (+IN), S2.2
unnamed: R15.1, R17.2, S3.3
unnamed: R9.2, R10.1, S2.7
unnamed: R11.1, S2.6
unnamed: R12.2, R13.1, S3.7
unnamed: R14.1, S3.6
unnamed: IC1.10 (+IN), S3.2
unnamed: R17.1, R18.2, S3.4
unnamed: IC1.6 (-IN), IC1.7 (OUT), R15.2, S3.1, TP5.TP
unnamed: IC1.9 (-IN), R19.1, R20.1, R21.1
unnamed: IC1.1 (OUT), IC1.2 (-IN)
unnamed: IC1.12 (+IN), R16.2, R23.1
unnamed: IC1.8 (OUT), R16.1, R19.2, R22.1, TP8.TP
unnamed: C9.1, IC1.13 (-IN), R24.1, TP7.TP
N&123: IC1.14 (OUT), R23.2, R25.1, TP6.TP
TL_PWM: R24.2; also elsewhere on the board
TRIG: R25.2; also elsewhere on the board
VSENSEL1: R11.2, TP3.TP; also elsewhere on the board
VSENSEL2: R14.2, TP4.TP; also elsewhere on the board

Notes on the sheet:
GND
10mV
0.1V

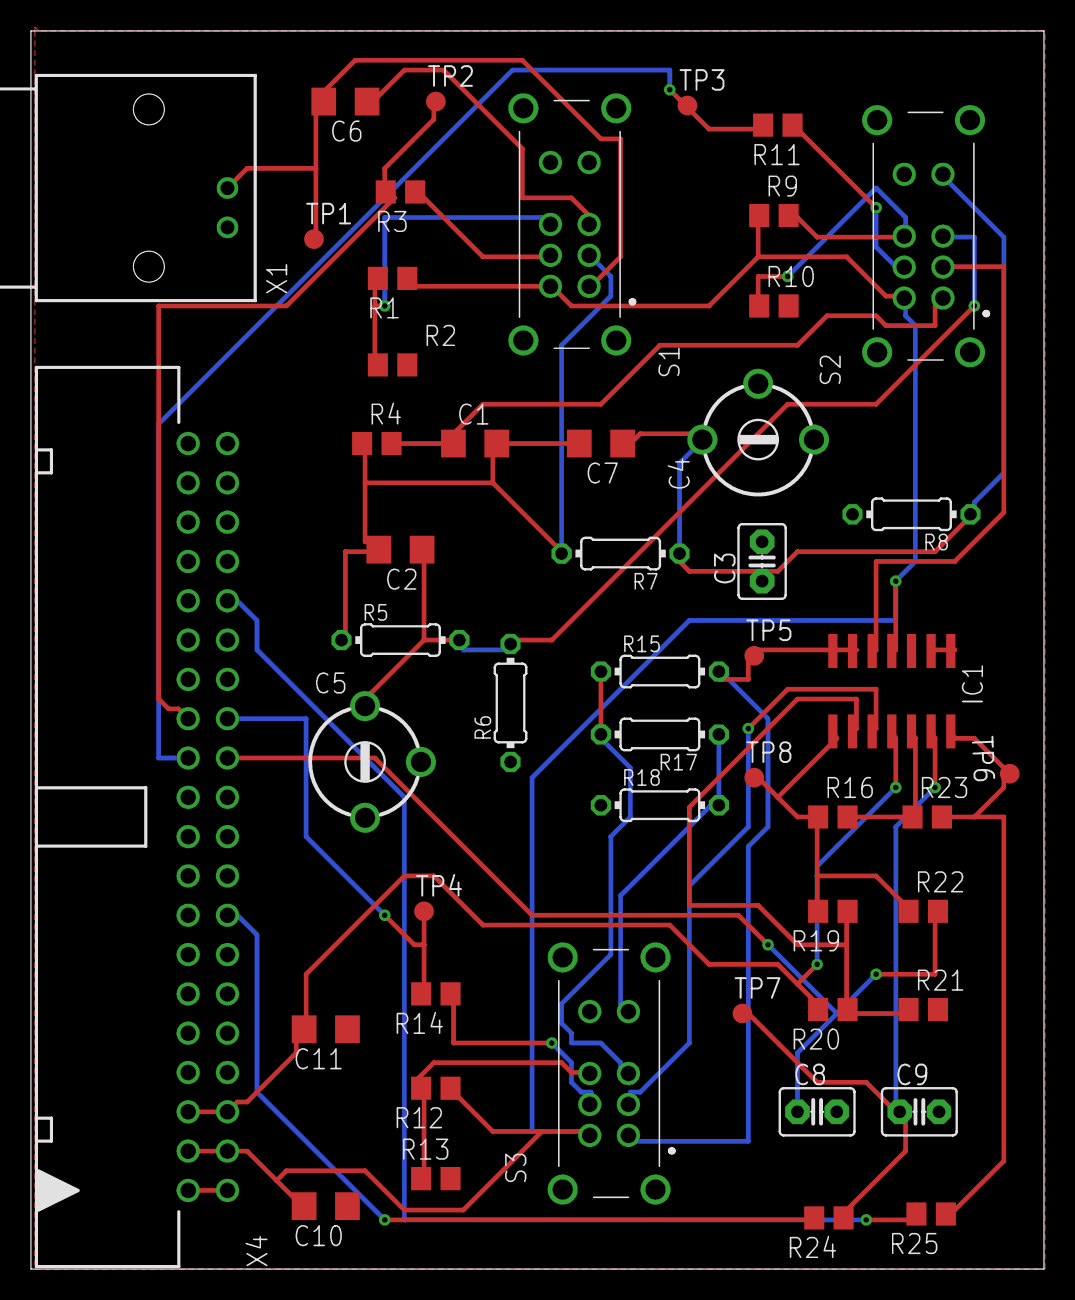
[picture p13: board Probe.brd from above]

Board: 2 copper layers, 65.5 x 80.0 mm, 50 parts (0 on the bottom side), 33 nets.

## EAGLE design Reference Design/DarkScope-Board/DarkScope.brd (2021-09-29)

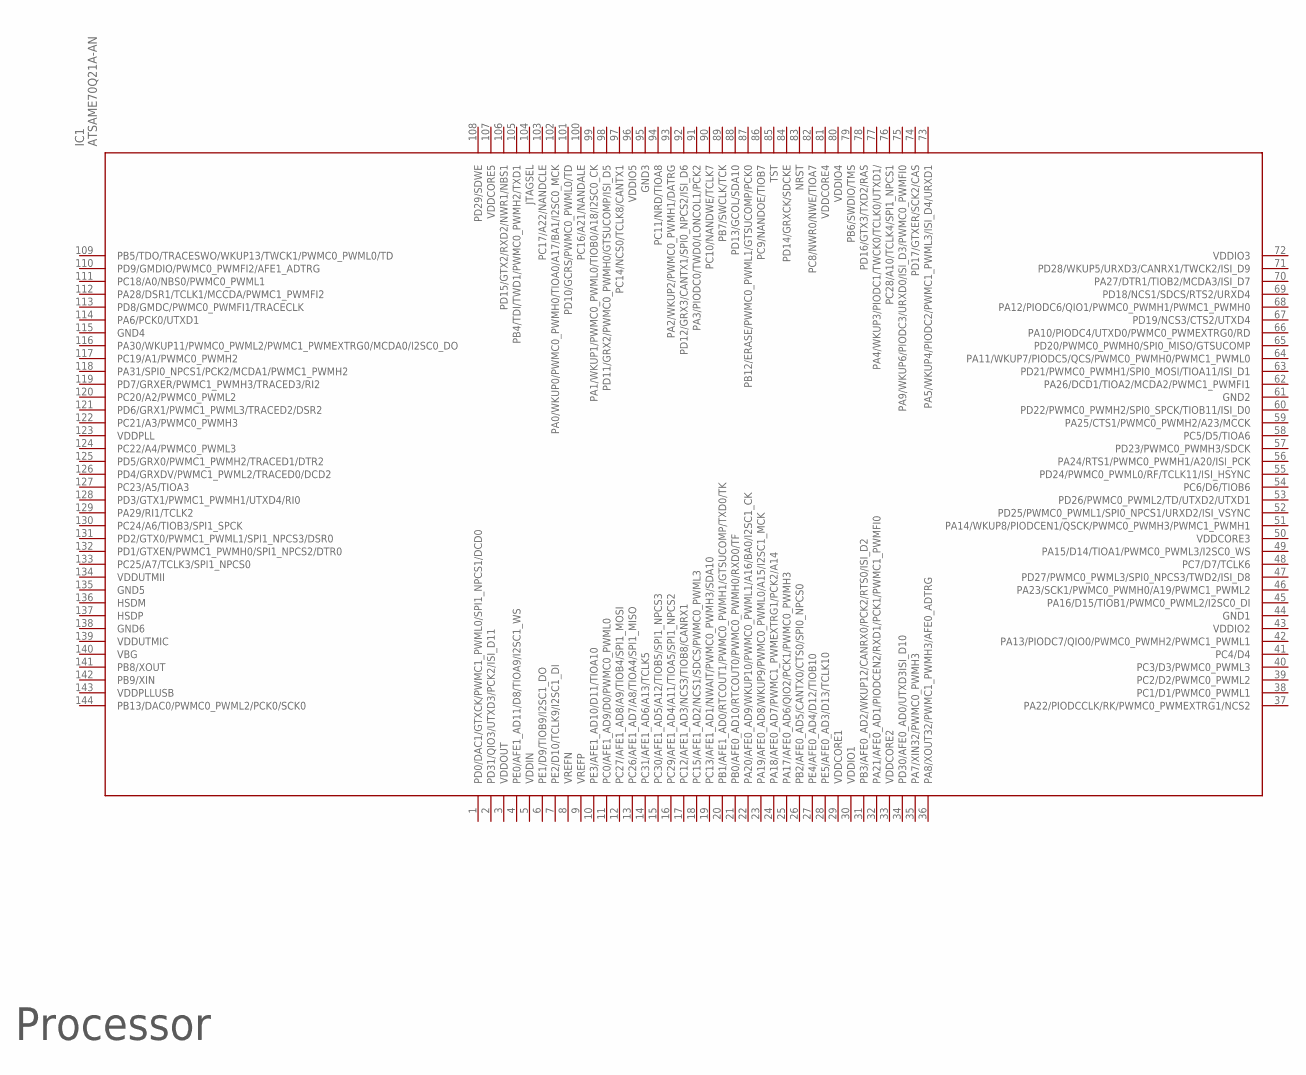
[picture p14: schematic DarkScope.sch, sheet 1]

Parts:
IC1: ATSAME70Q21A-AN; QFP50P2200X2200X160-144N

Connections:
GND1: IC1.44 (GND1)
GND2: IC1.61 (GND2)
GND3: IC1.95 (GND3)
GND4: IC1.115 (GND4)
GND5: IC1.135 (GND5)
GND6: IC1.138 (GND6)
VDDCORE1: IC1.29 (VDDCORE1)
VDDCORE2: IC1.33 (VDDCORE2)
VDDCORE3: IC1.50 (VDDCORE3)
VDDCORE4: IC1.81 (VDDCORE4)
VDDCORE5: IC1.107 (VDDCORE5)
VDDIN: IC1.5 (VDDIN)
VDDIO1: IC1.30 (VDDIO1)
VDDIO2: IC1.43 (VDDIO2)
VDDIO3: IC1.72 (VDDIO3)
VDDIO4: IC1.80 (VDDIO4)
VDDIO5: IC1.96 (VDDIO5)
VDDOUT: IC1.3 (VDDOUT)
VDDPLL: IC1.123 (VDDPLL)
VDDPLLUSB: IC1.143 (VDDPLLUSB)
VDDUTMIC: IC1.139 (VDDUTMIC)
VDDUTMII: IC1.134 (VDDUTMII)

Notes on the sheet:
Processor

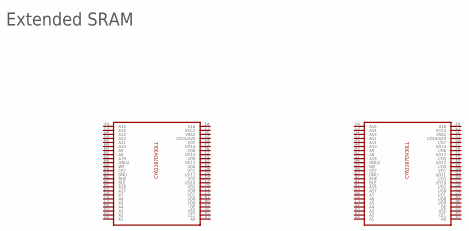
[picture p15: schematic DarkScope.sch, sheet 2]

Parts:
U$22, U$23: CY62167DV30LLCY62167DV30LL-55BVI; BGA48C75P6X8_950X800X100

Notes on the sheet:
Extended SRAM


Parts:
C1, C9: 0.1uf; C0603
C2: 220pf; C0603
C3: 3pf; C0603
C4: 1PF; C0603
C5, C6: 30pf; CTRIM3018_11
C7, C8: 120pf; C0603
D1, D4: ZENER-DIODESOD80C; SOD80C
D7: 3V3_Z_D; SOD80C
IC3, IC9: TLE2082ID; SOIC127P600X175-8N
JMP1: 0R-JUMPC; C0R-JMP
R1: 22K; R0603
R2, R22: 10K; R0603
R3, R16, R17: 100k; R0603
R4: 1.8M; R0603
R5: 2M; R0603
R6: 200k; R0603
R7: 20k; R0603
R8: 300; R0603
R9: 180; R0603
R10, R15: 120; R0603
R11, R18, R24, R25, R26, R27: 1k; R0603
R12: 3k; R0603
R13: 2.2K; R0603
R14: 330E; R0603
R21: 680E; R0603
R23: 68K; R0603
SJ1: SJ
T1, T2, T3, T4, T5, T6, T7, T8, T9, T10, T11, T12: BC807-40SMD; SOT23-BEC
TP1, TP2, TP3, TP4, TP5, TP6, TP7, TP8, TP9, TP10, TP11, TP12, TP13: TPTP07R; TP07R
X1: 1-227161-0; AMP_227161

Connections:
+5V/1: IC3.8 (VCC+), IC9.8 (VCC+), R12.2, TP7.TP, TP11.TP; also elsewhere on the board
GND: C5.- (A), C6.- (A), C7.2, C8.2, C9.2, D7.A, IC3.4 (VCC-), IC9.4 (VCC-), R6.2, R7.2, R10.2, R21.1, SJ1.1, T4.C; also elsewhere on the board
unnamed: R2.1, X1.2
unnamed: JMP1.1, R1.1, R2.2, TP12.TP
unnamed: C1.2, T3.C
unnamed: R8.2, R9.1, T8.C
unnamed: D4.C, R22.1, R23.2, T12.C, TP1.TP, TP13.TP, X1.1
unnamed: C2.1, C3.1, C4.1, R3.2, R4.2, R5.2, T2.E, T3.E, T4.E, TP2.TP
unnamed: C4.2, C6.+ (E), C7.1, R5.1, R7.1, T7.C
unnamed: C2.2, R3.1, T5.C
unnamed: C3.2, C5.+ (E), R4.1, R6.1, T6.C
unnamed: R9.2, R10.1, T9.C
unnamed: IC3.3 (1IN+), T5.E, T6.E, T7.E, TP3.TP
unnamed: IC3.5 (2IN+), T8.E, T9.E, T10.E, TP4.TP
unnamed: IC3.6 (2IN-), R11.1, R12.1, R13.2
unnamed: IC3.7 (2OUT), R11.2, R14.1, R15.2
unnamed: C8.1, R14.2, TP8.TP
unnamed: IC9.3 (1IN+), R15.1, R16.2
unnamed: IC9.1 (1OUT), R16.1, R18.2, TP6.TP
unnamed: C9.1, IC9.2 (1IN-), R17.2
unnamed: R17.1, TP10.TP
unnamed: R18.1, TP9.TP
unnamed: D7.C, IC3.1 (1OUT), IC3.2 (1IN-), R8.1, T10.C, TP5.TP
unnamed: R13.1, R21.2, SJ1.2
unnamed: R22.2, T1.E
unnamed: R1.2, R23.1
unnamed: JMP1.2, T1.C
unnamed: D1.A, R24.2, R25.2
unnamed: R25.1, T11.B
unnamed: D1.C, T11.C
unnamed: D4.A, R26.2, R27.2
unnamed: R27.1, T12.B
unnamed: C1.1, T2.C, T12.E

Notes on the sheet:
Probe Channel 1
HV Range Resistors
Changing the value of resistor R13 & R21 to 2.880K (2.2K + 680E) will toggle the 5V Peak output to 3V3 Peak .For 5V Levels the value is 1.5K(1.5K + Shorted SJ1)


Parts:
IC6, IC7: AT45DB161E-SSHD-T; SOIC127P600X175-8N

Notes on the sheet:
Internal Flash


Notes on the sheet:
USB Host (Thumb Drive) Section

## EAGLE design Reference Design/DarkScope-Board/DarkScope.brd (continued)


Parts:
IC8: MCP73871-2CAI_ML; QFN50P400X400X100-21N
NTC: 10K; R0603
PROG1: 2K2; R0603
PROG2: 10k; R0603
R74, R75, R76, R77: 10k; R0603
TP14, TP15, TP16, TP17, TP18, TP19, TP20, TP21: TPTP07R; TP07R
VBAT+: SMD5; SMD2,54-5,08
VBAT-/GND: SMD5; SMD2,54-5,08

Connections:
+5V: IC8.2 (VPCC), IC8.18 (IN), IC8.19 (IN_1), PROG2.2, R77.2, TP17.TP; also elsewhere on the board
BMC_PG: R76.1, TP19.TP
BMC_STAT1: R74.1, TP21.TP
BMC_STAT2: R75.1, TP20.TP
GND: IC8.10 (VSS), IC8.11 (VSS_1), PROG1.1, TP15.TP, VBAT-/GND.1; also elsewhere on the board
unnamed: IC8.8 (STAT1/!LBO), R74.2
unnamed: IC8.5 (THERM), NTC.2, TP18.TP
unnamed: IC8.6 (!PG), R76.2
unnamed: IC8.7 (STAT2), R75.2
unnamed: IC8.13 (PROG1), PROG1.2, TP16.TP
unnamed: IC8.14 (VBAT), IC8.15 (VBAT_1), IC8.16 (VBAT_SENSE), TP14.TP, VBAT+.1
unnamed: IC8.4 (PROG2), PROG2.1
unnamed: IC8.17 (CE), R77.1
VCC: IC8.1 (OUT), IC8.20 (OUT_1); also elsewhere on the board

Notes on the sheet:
Battery Management
Li-Ion Battery


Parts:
C37: 100uF Tantalum; C1206
D5, D6: SCHOTTKY-DIODESMC; DIODE_SMC
TP22, TP23, TP24, TP25, TP26: TPTP07R; TP07R
USB1: ZX62-B-5PA; MICRO-USB5+6P-SMD-0.65-AB

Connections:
+5V: C37.1, D5.C (A), D6.C (A), TP25.TP; also elsewhere on the board
GND: C37.2, TP26.TP, USB1.5 (GND), USB1.P1 (SHIELD), USB1.P2 (SHIELD), USB1.P3 (SHIELD), USB1.P4 (SHIELD), USB1.P5 (SHIELD), USB1.P6 (SHIELD); also elsewhere on the board
USBD+: TP23.TP, USB1.3 (D+)
USBD-: TP24.TP, USB1.2 (D-)
USBID: TP22.TP, USB1.4 (ID)
VBUS: D5.A (C), D6.A (C), USB1.1 (VBUS)

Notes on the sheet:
MicroUSB (For Charging and Data Transfer)


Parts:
C10, C12: 100uf; C0603K
C11, C13: 1uf; C0603K
C14, C15: C-USC0603K; C0603K
D2, D3: ss14; SMC
IC4, IC5: SP6641BEK-L-5-0; SOT95P280X145-5N
IC10: REG1117; SOT223
IC_VDD_SELECT: 0R-JUMPC; C0R-JMP
L1, L2: 10uH; 0204/7
R19, R20: 10E; R0603
T41: BC807-40SMD; SOT23-BEC
TP27, TP28, TP29, TP30, TP31, TP32: TPTP07R; TP07R

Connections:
3V3: T41.E, TP31.TP
3V3D: C15.1, IC10.2 (VOUT), T41.C, TP29.TP, TP32.TP
+3V3: C10.1, IC4.5 (VBATT), IC_VDD_SELECT.1, L1.2
+5V/1: C11.1, D2.C, IC_VDD_SELECT.3, R20.1, TP28.TP; also elsewhere on the board
+5V/2: C13.1, D3.C, R19.1, TP27.TP
CNTRL_3_3V: T41.B
GND: C10.2, C11.2, C12.2, C13.2, C14.2, C15.2, IC4.2 (GND), IC5.2 (GND), IC10.1 (GND); also elsewhere on the board
unnamed: D2.A, IC4.1 (LX), L1.1
unnamed: IC4.3 (VOUT), R20.2
unnamed: IC5.3 (VOUT), R19.2
unnamed: D3.A, IC5.1 (LX), L2.1
VCC: C12.1, C14.1, IC5.5 (VBATT), IC10.3 (VIN), L2.2, TP30.TP; also elsewhere on the board
VCCINT: IC_VDD_SELECT.2

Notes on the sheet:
Power Supply and Input Regulation
3.3V Peripheral Power Control
5V Power for ICs
5V Power for Relays and Power Electronics
3V3 Regulator Circuit
VINT Voltage Source Selection

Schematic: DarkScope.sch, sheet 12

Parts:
SD1: ST-TF-003A; MICRO-SD9+4P-SMD-16.1X14.5X1.85MM

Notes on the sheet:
MicroSD Section

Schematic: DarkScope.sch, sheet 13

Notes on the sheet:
Switching Circuitry

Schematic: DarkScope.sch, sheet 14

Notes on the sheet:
RCA Out

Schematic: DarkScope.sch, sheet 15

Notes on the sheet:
VGA Out

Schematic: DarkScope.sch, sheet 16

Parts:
U$20, U$21: MAX19516ETM+MAX19516ETM+; QFN50P700X700X80-48

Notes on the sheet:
HIGH SPEED ADC
Channel 1
Channel 2

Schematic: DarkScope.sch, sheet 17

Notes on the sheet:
4.5"/7" LCD

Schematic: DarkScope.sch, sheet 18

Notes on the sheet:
Sample Wave

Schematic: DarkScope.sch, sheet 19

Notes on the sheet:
Switches

Board: 2 copper layers, 125 parts (0 on the bottom side), 58 nets, no tracks yet.

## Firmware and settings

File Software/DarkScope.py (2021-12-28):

# importing various libraries
import sys
from PyQt5 import QtGui, QtWidgets
from PyQt5 import QtCore
from PyQt5.QtCore import QRect
from PyQt5.QtWidgets import QCheckBox, QComboBox, QDialog, QApplication, QDoubleSpinBox, QHBoxLayout, QLabel, QPushButton, QSpacerItem, QSpinBox, QVBoxLayout
from matplotlib.backends.backend_qt5agg import FigureCanvasQTAgg as FigureCanvas
from matplotlib.backends.backend_qt5agg import NavigationToolbar2QT as NavigationToolbar
import matplotlib.pyplot as plt
import random
import serial
import serial.tools.list_ports as ports

# main window
# which inherits QDialog
class Window(QDialog):
    sense1 = 0
    sense2 = 0
    cplsel = 0

    mult1 = 0.010
    mult2 = 1

    adcmultMap = [5, 2, 1, 0.5, 0.2, 0.1, 0.05, 0.02, 0.01]
    adcMultiplier = [0.05085, 0.02034, 0.01017, 0.005085, 0.002034, 0.001017, 0.5085, 0.2034, 0.1017]
    mulIndex = 0

    graphdata = []

    def closeEvent(self, a0: QtGui.QCloseEvent) -> None:
        try:
            if(self.ser.is_open):
                print("Disconnected to Port Successfully")
                self.ser.close()
        except:
            pass
        return super().closeEvent(a0)

    def initConnect(self):
        self.ser = serial.Serial(self.COMport.currentText(), 250000, timeout=0)
        if self.ser.is_open:
            print("Connected to Port Successfully")
            self.connectionState.setText("Connected Successfully")
            self.startLoop()

    def startLoop(self):
        # loop
        self.timer = QtCore.QTimer(self)
        self.timer.timeout.connect(self.updateData)
        self.timer.start(1)

    def stopLoop(self):
        try:
            self.timer.stop()
        except:
            pass
    
    def resumeLoop(self):
        try:
            self.timer.start(1)
        except:
            pass

    def updateGraphLimits(self):
        if(self.sense1 == 0 and self.sense2 == 0):
            self.mulIndex = 0
        elif(self.sense1 == 0 and self.sense2 == 1):
            self.mulIndex = 1
        elif(self.sense1 == 0 and self.sense2 == 2):
            self.mulIndex = 2
        elif(self.sense1 == 1 and self.sense2 == 0):
            self.mulIndex = 3
        elif(self.sense1 == 1 and self.sense2 == 1):
            self.mulIndex = 4
        elif(self.sense1 == 1 and self.sense2 == 2):
            self.mulIndex = 5
        elif(self.sense1 == 2 and self.sense2 == 0):
            self.mulIndex = 6
        elif(self.sense1 == 2 and self.sense2 == 1):
            self.mulIndex = 7
        elif(self.sense1 == 2 and self.sense2 == 2):
            self.mulIndex = 8

        # plt.ylim([-1 * self.mult1 * self.mult2, self.mult1 * self.mult2])

    # Fetch and Update Data and Switch Positions and Labels Accordingly
    # to be called at same rate at which data is bieng recieved by DarkScope - 500Hz or Faster
    def updateData(self):
        if not self.ser.is_open:
            return

        self.ser.flush()
        line = self.ser.readline()
        # to debug
        #print("data-", line)
        if(b'f' in line[:1]):
            try:
                mydata = [(self.adcMultiplier[self.mulIndex] * (int(i)-2048)) for i in str(line[1:]).split(",")[1:][:-1]]
                #print("mydata", mydata)
                self.graphdata = mydata
                self.plot(False)
            except(ValueError):
                pass
        elif(b's1' in line[:2]):
            self.sense1 = int(line[3:])
            self.updateGraphLimits()
            print("s1-", self.sense1)
        elif(b's2' in line[:2]):
            self.sense2 = int(line[3:])
            self.updateGraphLimits()
            print("s2-", self.sense2)
        elif(b's3' in line[:2]):
            self.updateGraphLimits()
            self.cplsel = int(line[3:])
            print("s3-", self.cplsel)
        else:
            pass  

    # constructor
    def __init__(self, parent=None):
        super(Window, self).__init__(parent)
   
        self.setWindowTitle("DarkScope Host Software")

        # a figure instance to plot on
        self.figure = plt.figure()
   
        # this is the Canvas Widget that 
        # displays the 'figure'it takes the
        # 'figure' instance as a parameter to __init__
        self.canvas = FigureCanvas(self.figure)
   
        # this is the Navigation widget
        # it takes the Canvas widget and a parent
        self.toolbar = NavigationToolbar(self.canvas, self)
   
        # Just some button connected to 'plot' method
        self.button = QPushButton('Demo Push')
           
        # adding action to the button
        self.button.clicked.connect(lambda: self.plot(True))

        # Toolbox Layout
        master_toolbox = QVBoxLayout()
        master_toolbox.addItem(QSpacerItem(20, 40, QtWidgets.QSizePolicy.Minimum, 40))

        self.devSelectLayout = QVBoxLayout()
        self.devSelectLayout.addWidget(QLabel("Select COM Port"))
        self.COMport = QComboBox()
        com_ports = list(ports.comports())
        for x in com_ports:
            self.COMport.addItem(x.device)
        self.connectButton = QPushButton("Connect")
        self.connectionState = QLabel("Not Connected")
        self.devSelectLayout.addWidget(self.COMport)
        self.devSelectLayout.addWidget(self.connectButton)
        self.devSelectLayout.addWidget(self.connectionState)
        master_toolbox.addLayout(self.devSelectLayout)
        master_toolbox.addItem(QSpacerItem(20, 40, QtWidgets.QSizePolicy.Minimum, 40))

        master_toolbox.addWidget(QLabel("Channel Selection :"))
        self.chlayout = QHBoxLayout()
        self.ch1 = QPushButton('A')
        self.ch2 = QPushButton('B')
        self.ch3 = QPushButton('C')
        self.ch4 = QPushButton('D')
        self.chlayout.addWidget(self.ch1)
        self.chlayout.addWidget(self.ch2)
        self.chlayout.addWidget(self.ch3)
        self.chlayout.addWidget(self.ch4)
        master_toolbox.addLayout(self.chlayout)
        master_toolbox.addItem(QSpacerItem(20, 40, QtWidgets.QSizePolicy.Minimum, 40))

        self.chInfoLayout = QVBoxLayout()
        self.enable_channel = QCheckBox("Enable Channel")
        self.Senstivity = QLabel("Senstivity: 2V/Div")
        self.Coupling = QLabel("Coupling: AC")
        self.Sampling = QLabel("Sampling: 2048 Samples")
        self.Buffer = QLabel("Buffer: 2048 Samples")
        self.chInfoLayout.addWidget(self.enable_channel)
        self.chInfoLayout.addWidget(self.Senstivity)
        self.chInfoLayout.addWidget(self.Coupling)
        self.chInfoLayout.addWidget(self.Sampling)
        self.chInfoLayout.addWidget(self.Buffer)
        master_toolbox.addLayout(self.chInfoLayout)
        master_toolbox.addItem(QSpacerItem(20, 40, QtWidgets.QSizePolicy.Minimum, 40))

        self.trModeLayout = QVBoxLayout()
        self.triggermode_label = QLabel("Trigger Mode")
        self.triggermode = QComboBox()
        self.triggermode.addItem("Auto")
        self.triggermode.addItem("Mannual")
        self.manualTriggerVoltage = QDoubleSpinBox()
        self.manualTriggerVoltage.setRange(-50, 50)
        self.manualTriggerVoltage.setSuffix(" Volts")
        self.triggerType_label = QLabel("Mannual Trigger Type")
        self.triggerType = QComboBox()
        self.triggerType.addItem("Falling Edge")
        self.triggerType.addItem("Rising Edge")

        self.trModeLayout.addWidget(self.triggermode_label)
        self.trModeLayout.addWidget(self.triggermode)
        self.trModeLayout.addWidget(QLabel("Manual Trigger Voltage"))
        self.trModeLayout.addWidget(self.manualTriggerVoltage)
        self.trModeLayout.addWidget(self.triggerType_label)
        self.trModeLayout.addWidget(self.triggerType)
        master_toolbox.addLayout(self.trModeLayout)
        master_toolbox.addItem(QSpacerItem(20, 40, QtWidgets.QSizePolicy.Minimum, 40))

        self.actionbuttonsLayout = QHBoxLayout()
        self.button_Run = QPushButton("Run")
        self.button_Stop = QPushButton("Stop")
        self.button_autotrigger = QPushButton("Auto Trigger")
        self.actionbuttonsLayout.addWidget(self.button_Run)
        self.actionbuttonsLayout.addWidget(self.button_Stop)
        self.actionbuttonsLayout.addWidget(self.button_autotrigger)
        master_toolbox.addLayout(self.actionbuttonsLayout)
        master_toolbox.addItem(QSpacerItem(20, 40, QtWidgets.QSizePolicy.Minimum, QtWidgets.QSizePolicy.Expanding))

        self.appCloseButton = QPushButton("Close Application")
        master_toolbox.addWidget(QLabel("Host Application Developed By Yatin Khurana\n 00514807319, MAIT, 7ECE-E1"))
        master_toolbox.addWidget(self.appCloseButton)

        # creating a Vertical Box layout
        layout = QHBoxLayout()

        graph =  QVBoxLayout()  
        # adding tool bar to the layout
        graph.addWidget(self.toolbar)
           
        # adding canvas to the layout
        graph.addWidget(self.canvas)
           
        # adding push button to the layout
        graph.addWidget(self.button)
        layout.addLayout(graph)
        layout.addLayout(master_toolbox)
           
        # Widget Connections
        self.appCloseButton.clicked.connect(self.close)
        self.connectButton.clicked.connect(self.initConnect)
        self.button_Run.clicked.connect(self.resumeLoop)
        self.button_Stop.clicked.connect(self.stopLoop)
        
        # setting layout to the main window
        self.setLayout(layout)
   
    # action called by thte push button
    def plot(self, _random):
        
        if(_random):
            # random data
            self.graphdata = [random.random() for i in range(2048)]
   
        # clearing old figure
        self.figure.clear()
   
        # create an axis
        ax = self.figure.add_subplot(111)
   
        # plot data
        ax.plot(self.graphdata, '.-')
        #plt.ylim([-1 * self.adcMultiplier[self.mulIndex] * 2048, self.adcMultiplier[self.mulIndex] * 2048])

        ax.grid()
   
        # refresh canvas
        self.canvas.draw()
   
# driver code
if __name__ == '__main__':
       
    # creating apyqt5 application
    app = QApplication(sys.argv)
   
    # creating a window object
    main = Window()
       
    # showing the window
    main.show()

    main.showFullScreen()

    sys.exit(app.exec_())

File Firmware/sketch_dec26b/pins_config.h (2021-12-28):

#define SERIAL_BAUD_RATE	250000

// analog and digital samples storage depth
#define NUM_SAMPLES 	2048	

// pin definitions (DSO138)
#define BOARD_LED 		PA15
#define TEST_WAVE_PIN 	PA7     // 1KHz square wave output
#define TRIGGER_IN		PA8
#define TRIGGER_LEVEL	PB8
#define VGEN			PB9		// used to generate negative voltage in DSO138

// captured inputs
#define AN_CH1 			PA0		// analog channel 1
#define AN_CH2 			PA4		// analog channel 2
#define DG_CH1 			PA13	// digital channel 1 - 5V tolerant pin. Pin mask throughout code has to match digital pin
#define DG_CH2 			PA14	// digital channel 2 - 5V tolerant pin. Pin mask throughout code has to match digital pin

// misc analog inputs
#define VSENSSEL1 		PA2
#define VSENSSEL2		PA1
#define CPLSEL			PA3

#define LED_ON	digitalWrite(BOARD_LED, LOW)
#define LED_OFF	digitalWrite(BOARD_LED, HIGH)

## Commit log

2021-09-29 CP Added MCU and Supporting Periph
    [BaseBoard.sch, DarkScope.brd, DarkScope.sch]
2021-09-30 CP PSU
    [BaseBoard.sch]
2021-09-30 CP PSU Completed
    [BaseBoard.sch]
2021-10-01 Added LCD Header
    [BaseBoard.sch]
2021-10-17 BaseBoard Schematic Complete
    [BaseBoard.sch]
2021-10-23 BB DP
    [BaseBoard.brd, BaseBoard.sch]
2021-10-23 CP Component Placements
    [BaseBoard.brd, BaseBoard.sch]
2021-10-23 Cp BB Placement Completed
    [BaseBoard.brd]
2021-10-23 UnRouted Board Bkp
    [BaseBoard.brd, BaseBoard.sch]
2021-10-23 CP BB PCB Draft
    [BaseBoard.brd]
2021-10-23 Added Mounting Holes
    [BaseBoard.brd]
2021-10-23 Added PCB Holes for Mounting
    [BaseBoard.brd]
2021-10-24 Sim Model DP
    [Probe.sch]
2021-11-16 DP Probe SCH
    [Probe.sch]
2021-11-17 Drafted Sch for Probe Board
    [BaseBoard.brd, BaseBoard.sch, Probe.sch]
2021-11-17 DP wtf
    [Probe.sch]
2021-11-18 Fixed baseboard
    [BaseBoard.brd]
2021-11-19 Unrouted Probe Board
    [Probe.brd, Probe.sch]
2021-11-19 Routed Probe Board
    [Probe.brd]
2021-11-19 Cleared and Fixed Probe Board's ERC Errors
    [Probe.brd, Probe.sch]
2021-12-10 Updated Board Dimension and Added Gerbers
    [BaseBoard.brd, BaseBoard.sch]
2021-12-10 Fixed BaseBoard Bugs
    1. Ground Plane Not connected Properly
    2. C14,C15 Reversed.
    [BaseBoard.brd, BaseBoard.sch]
2021-12-10 Added Final Probe CAM Outputs
2021-12-10 Added BOMs
    [BaseBoardBOM.csv, ProbeBOM.csv]
2021-12-12 Updated BaseBoard as per DFM Request
    [BaseBoard.brd, BaseBoard.sch]
